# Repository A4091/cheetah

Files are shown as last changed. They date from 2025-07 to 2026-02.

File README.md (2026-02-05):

# A4770 Cheetah

A modern successor to the A4091 / A4092.

All the goodness of the A4092:
* TSSOP parts for smaller footprint
* SPI Flash instead of parallel EPROM
* CPLD instead of GALs
* Autoconfig moved into CPLD

And also:
* Update to NCR53c770 SCSI Host Controller
* Ultra-Wide SCSI support
* Drop unneeded ferrites and capacitors on SCSI lines
* Replace DIP-switch mechanism entirely w/ Software/Logic
* No more resistor arrays

# THIS IS WORK IN PROGRESS. DO NOT BUILD. FEEDBACK IS WELCOME

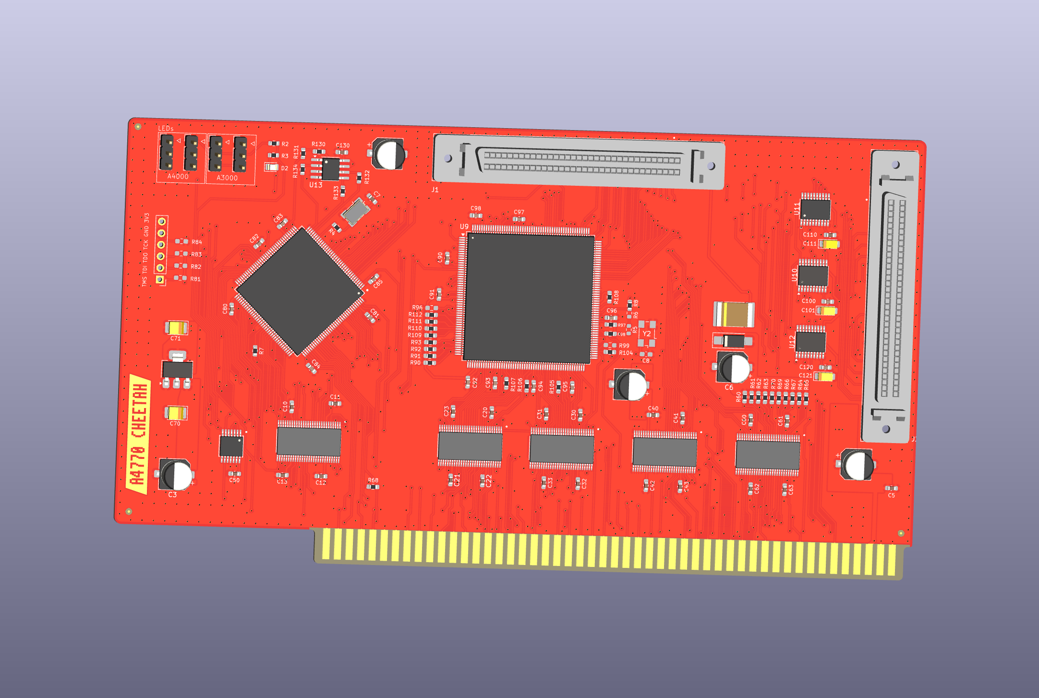
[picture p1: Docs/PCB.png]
PCB


<!-- ![PCB](Docs/PCB.png?raw=True)

And also as a real PCB:

![Real PCB](Docs/PCB.jpg?raw=True)

-->

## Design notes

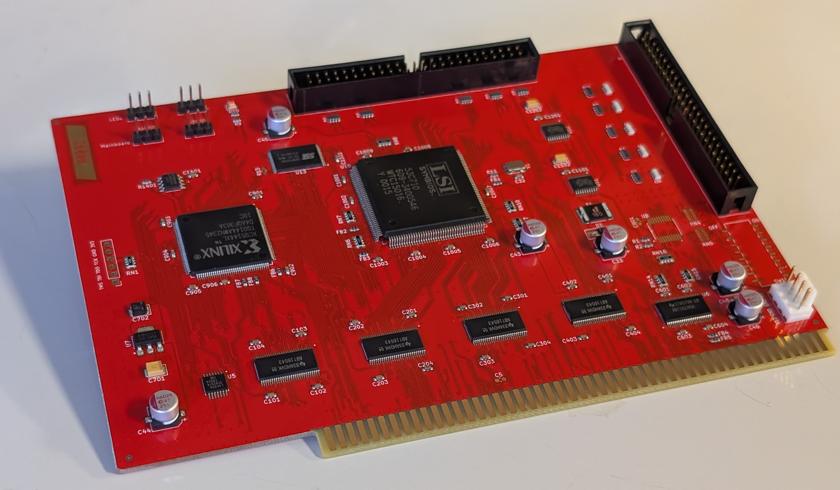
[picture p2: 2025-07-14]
Docs/PCB.jpg

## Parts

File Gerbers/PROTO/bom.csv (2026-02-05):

Designator | Footprint | Quantity | Value | LCSC Part #
C1, C2, C3, C4, C6 | CP_Elec_6.3x7.7 | 5 | 47uF | C369909
C10, C100, C11, C110, C12, C120, C13, C130, C20, C21, C22, C23, C30, C31, C32, C33, C40, C41, C42, C43, C5, C50, C60, C61, C62, C63, C80, C81, C82, C83, C84, C85, C90, C92, C94, C96, C98 | 0603 | 37 | 100nF | C14663
C101, C111, C121 | CP_EIA-3216-10_Kemet-I_HandSolder | 3 | 4.7uF | C7189
C7 | 0603 | 1 | 10nF | C57112
C70 | CP_EIA-3528-15_AVX-H_HandSolder | 1 | 10uF | C7194
C71 | CP_EIA-3528-15_AVX-H_HandSolder | 1 | 22uF | C696813
C91, C93, C95, C97 | 0603 | 4 | 100nF | C57112
D1 | D_SMA_Handsoldering | 1 | SS24 | C43381
D2 | 0805 | 1 | LED (green) | C965821
F1 | 2920 | 1 | ASMDC185F/33-2 | C135379
J1 | TE_5749721-7 | 1 | 5749721-7 | C591675
J2 | TE_5749721-7 | 1 | 5787082-7 | C591676
J3 | PinHeader_1x03_P2.54mm_Vertical | 1 | TO-LED | C6332196
J4 | PinHeader_1x03_P2.54mm_Vertical | 1 | TO-MB | C6332196
J5 | PinHeader_1x03_P2.54mm_Vertical | 1 | TO-A3000-LED | C6332196
J6 | PinHeader_1x03_P2.54mm_Vertical | 1 | TO-A3000-MB | C6332196
J8 | PinHeader_1x06_P2.54mm_Vertical | 1 | Conn_01x06_Pin | C6332199
R104, R105, R106, R107, R60, R61, R62, R63, R64, R65, R66, R67, R68, R69, R70, R90, R91, R92, R93, R96, R97, R98, R99 | 0603 | 23 | 1K | C21190
R108, R109, R110, R111, R112, R130, R81, R82, R83, R84 | 0603 | 10 | 10K | C25804
R131, R132, R133 | 0603 | 3 | 33 | C23140
R134, R8 | 0603 | 2 | 0 | C21189
R2 | 0603 | 1 | 120 | C22787
R3 | 0603 | 1 | 2.2k | C4190
R4, R7 | 0603 | 2 | 22 | C23345
U1, U2, U3, U4, U6 | DGG56 | 5 | SN74ABT16543DGGR | C2865087
U10, U11, U12 | TSSOP-20_4.4x6.5mm_P0.65mm | 3 | DS21S07A | C6602097
U13 | SOIC-8_multi | 1 | W25X40CLSN | C19617
U5 | TSSOP14_5P1X4P5_NEX | 1 | 74LVC07APW_118 | C6051
U7 | SOT-223-3_TabPin2 | 1 | AMS1117-3.3 | C6186
U8 | 144-TQFP_XIL | 1 | XC95144XL-TQ144 | C1521137
U9 | PQFP-208_28x28mm_P0.5mm | 1 | LSI53C770 SCSI Host Controller | C9900193416
Y1 | Oscillator_SMD_Fox_FT5H_5.0x3.2mm | 1 | Abracon ACO-50MHz | C7431196

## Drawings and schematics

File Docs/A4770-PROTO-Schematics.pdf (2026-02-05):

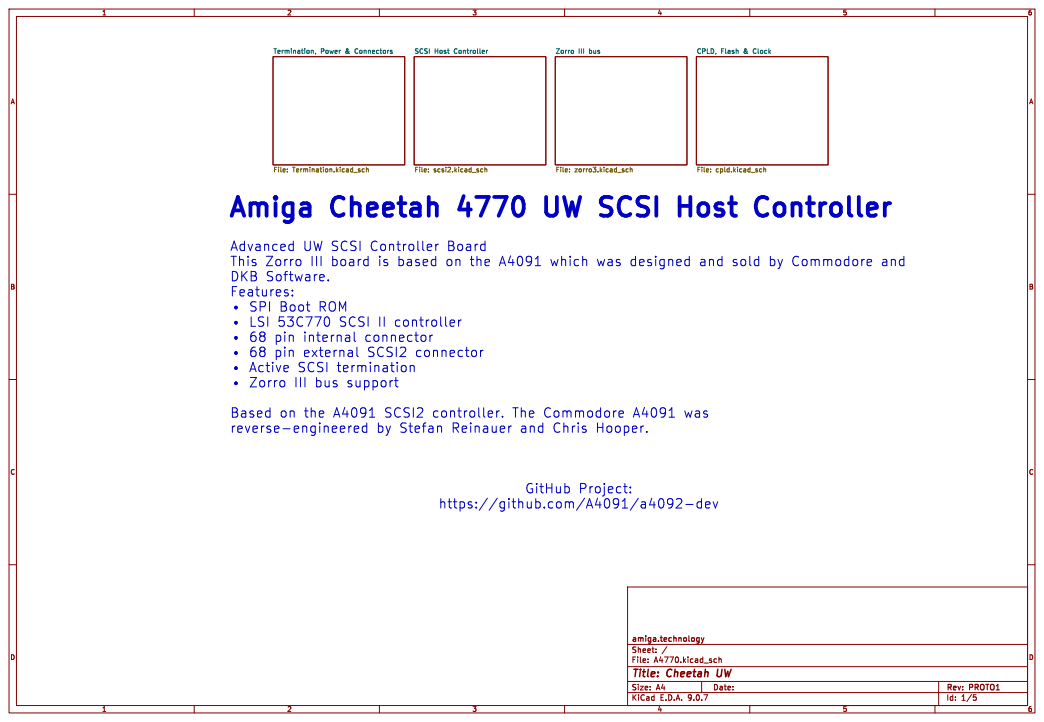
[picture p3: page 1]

Amiga Cheetah 4770 UW SCSI Host Controller

https://github.com/A4091/a4092-dev

File: A4770.kicad_sch Sheet: / amiga.technology

Id: 1/5 Title: Cheetah UW

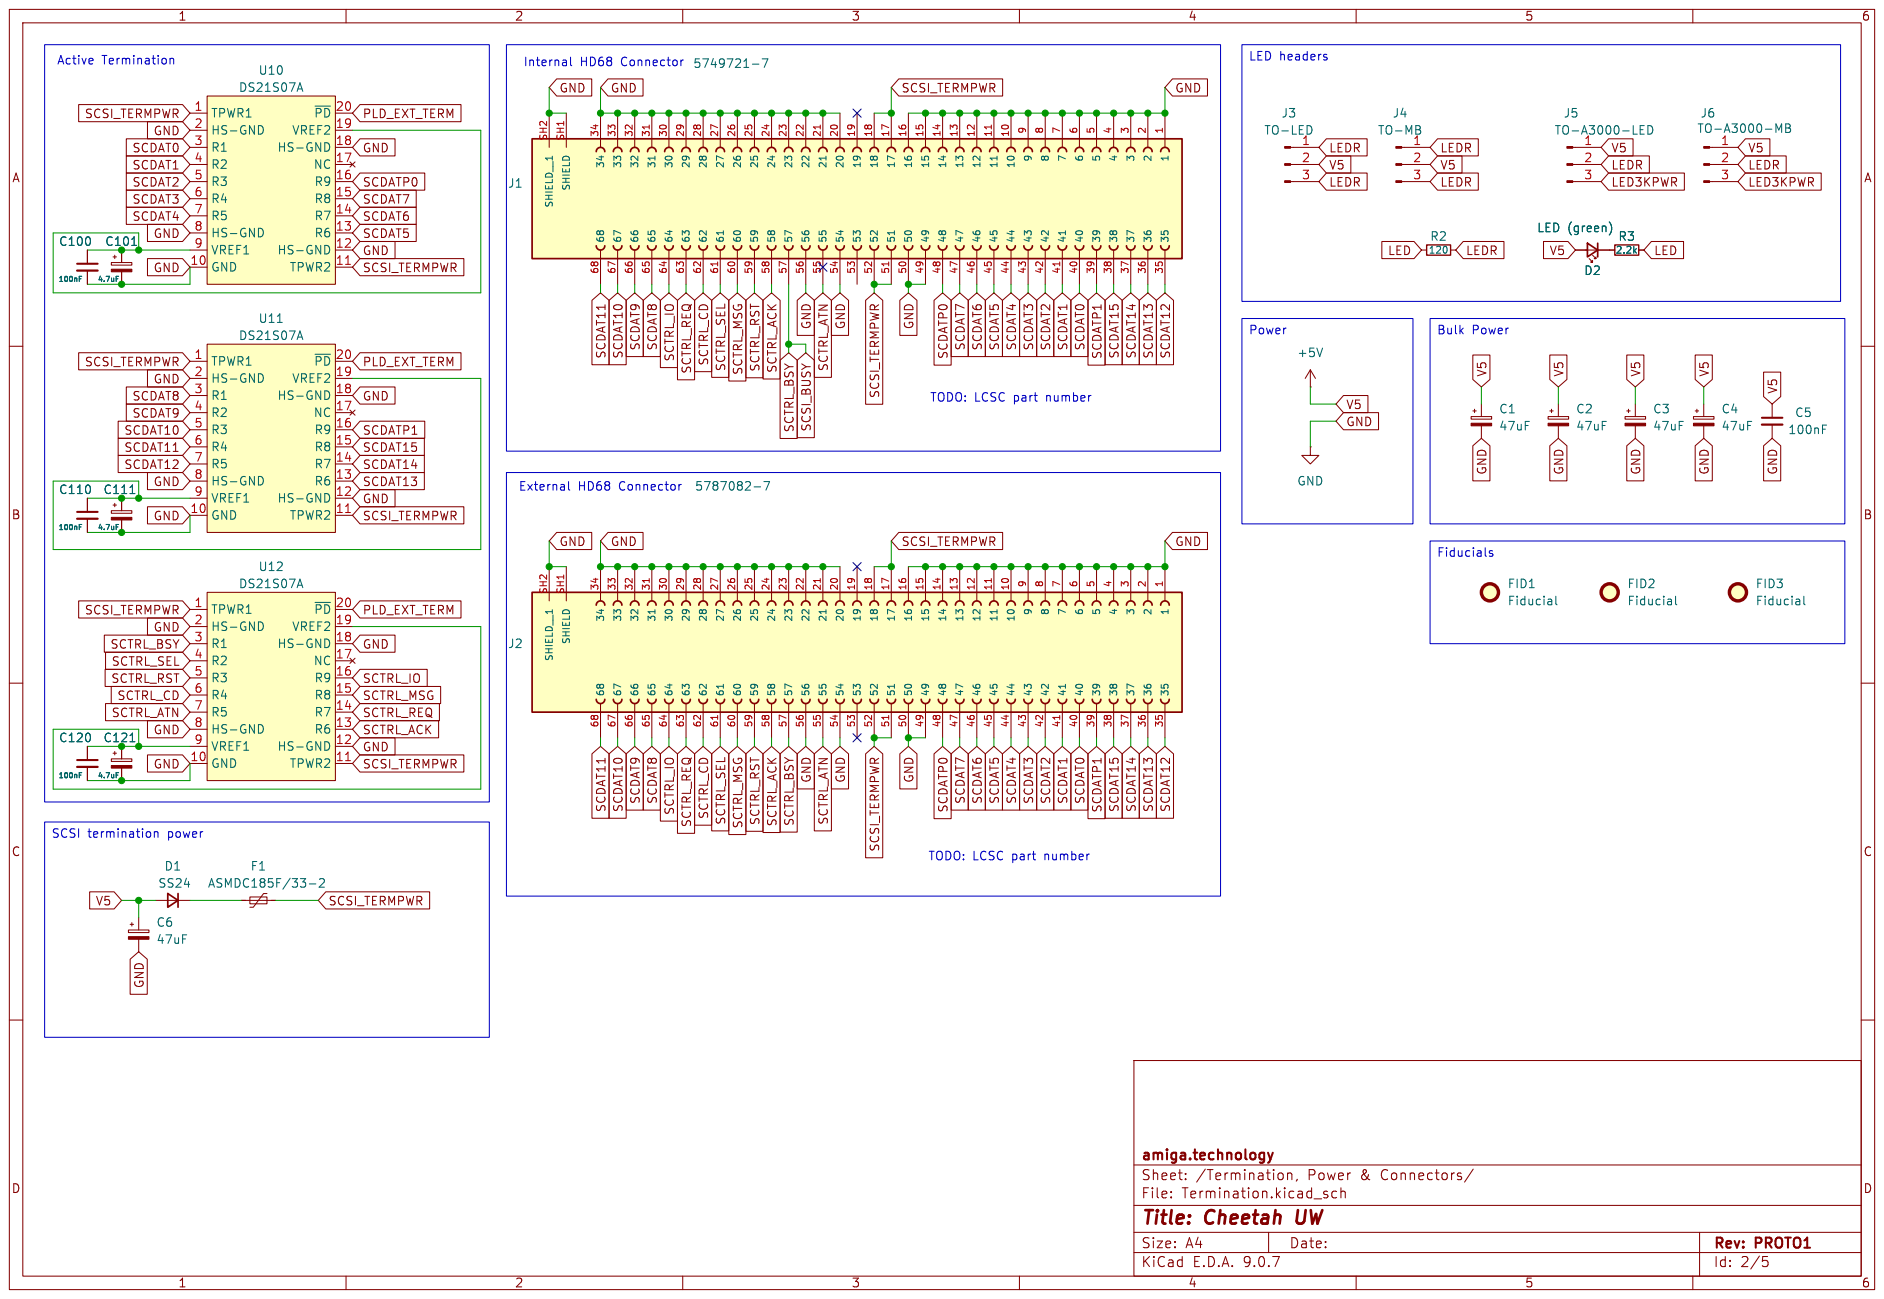
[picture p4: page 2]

LED headers Power External HD68 Connector Active Termination
SCSI_TERMPWR GND GND GND

TODO: LCSC part number

Id: 2/5 Title: Cheetah UW

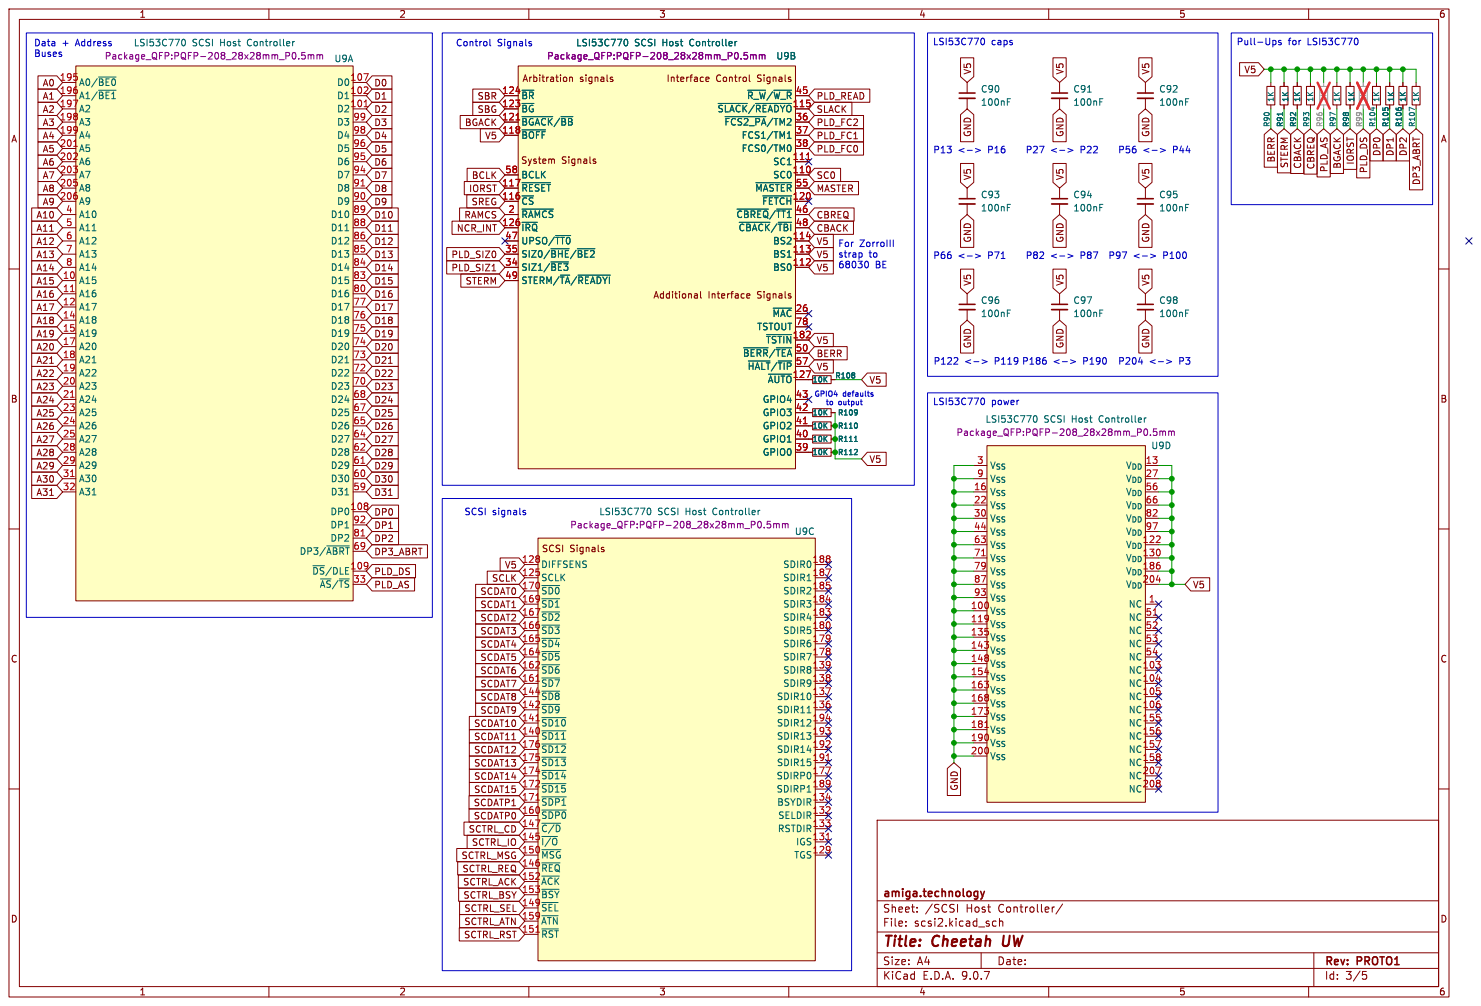
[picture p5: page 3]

Id: 3/5 Title: Cheetah UW

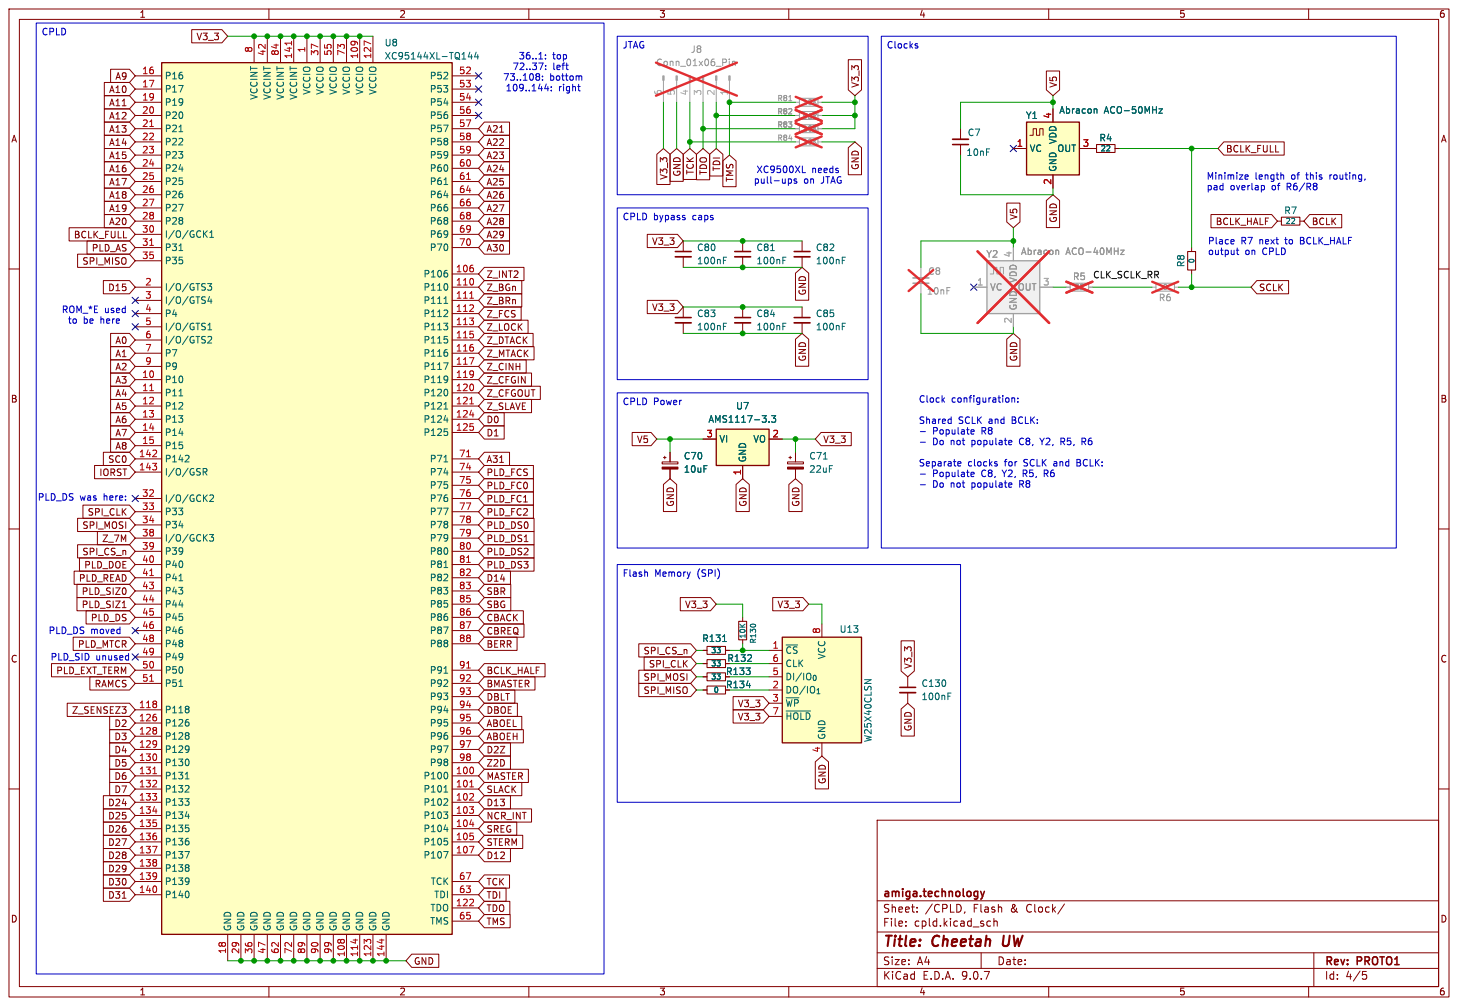
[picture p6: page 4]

8 GND 36 VCCINT 42 GND 47 VCCINT 84 GND 62 VCCINT 141 GND 72 VCCIO

1 GND 89 VCCIO 37 GND 90 VCCIO 55 GND 99 VCCIO 73 GND 108 VCCIO 109 GND 114 VCCIO 127 GND 123 GND 144 P52 52 P53 53 P54 54 P56 56 P57 57 P58 58 P59 59 P60 60 P61 61 P64 64 P66 66 P68 68 P69 69 P70 70 P106 106 P110 110 P111 111 P112 112 P113 113 P115 115 P116 116 P117 117 P119 119 P120 120 P121 121 P124 124 P125 125 P71 71 P74 74 P75 75 P76 76 P77 77 P78 78 P79 79 P80 80 P81 81 P82 82 P83 83 P85 85 P86 86 P87 87 P88 88 P91 91 P92 92 P93 93 P94 94 P95 95 P96 96 P97 97 P98 98 P100 100 P101 101 P102 102 P103 103 P104 104 P105 105 P107 107 TCK 67 TDI 63 TDO 122 TMS 65

JTAG
CPLD Power CPLD bypass caps

pad overlap of R6/R8 PLD_DS was here:
IORSTA3 A18

output on CPLD Minimize length of this routing,

Id: 4/5 Title: Cheetah UW

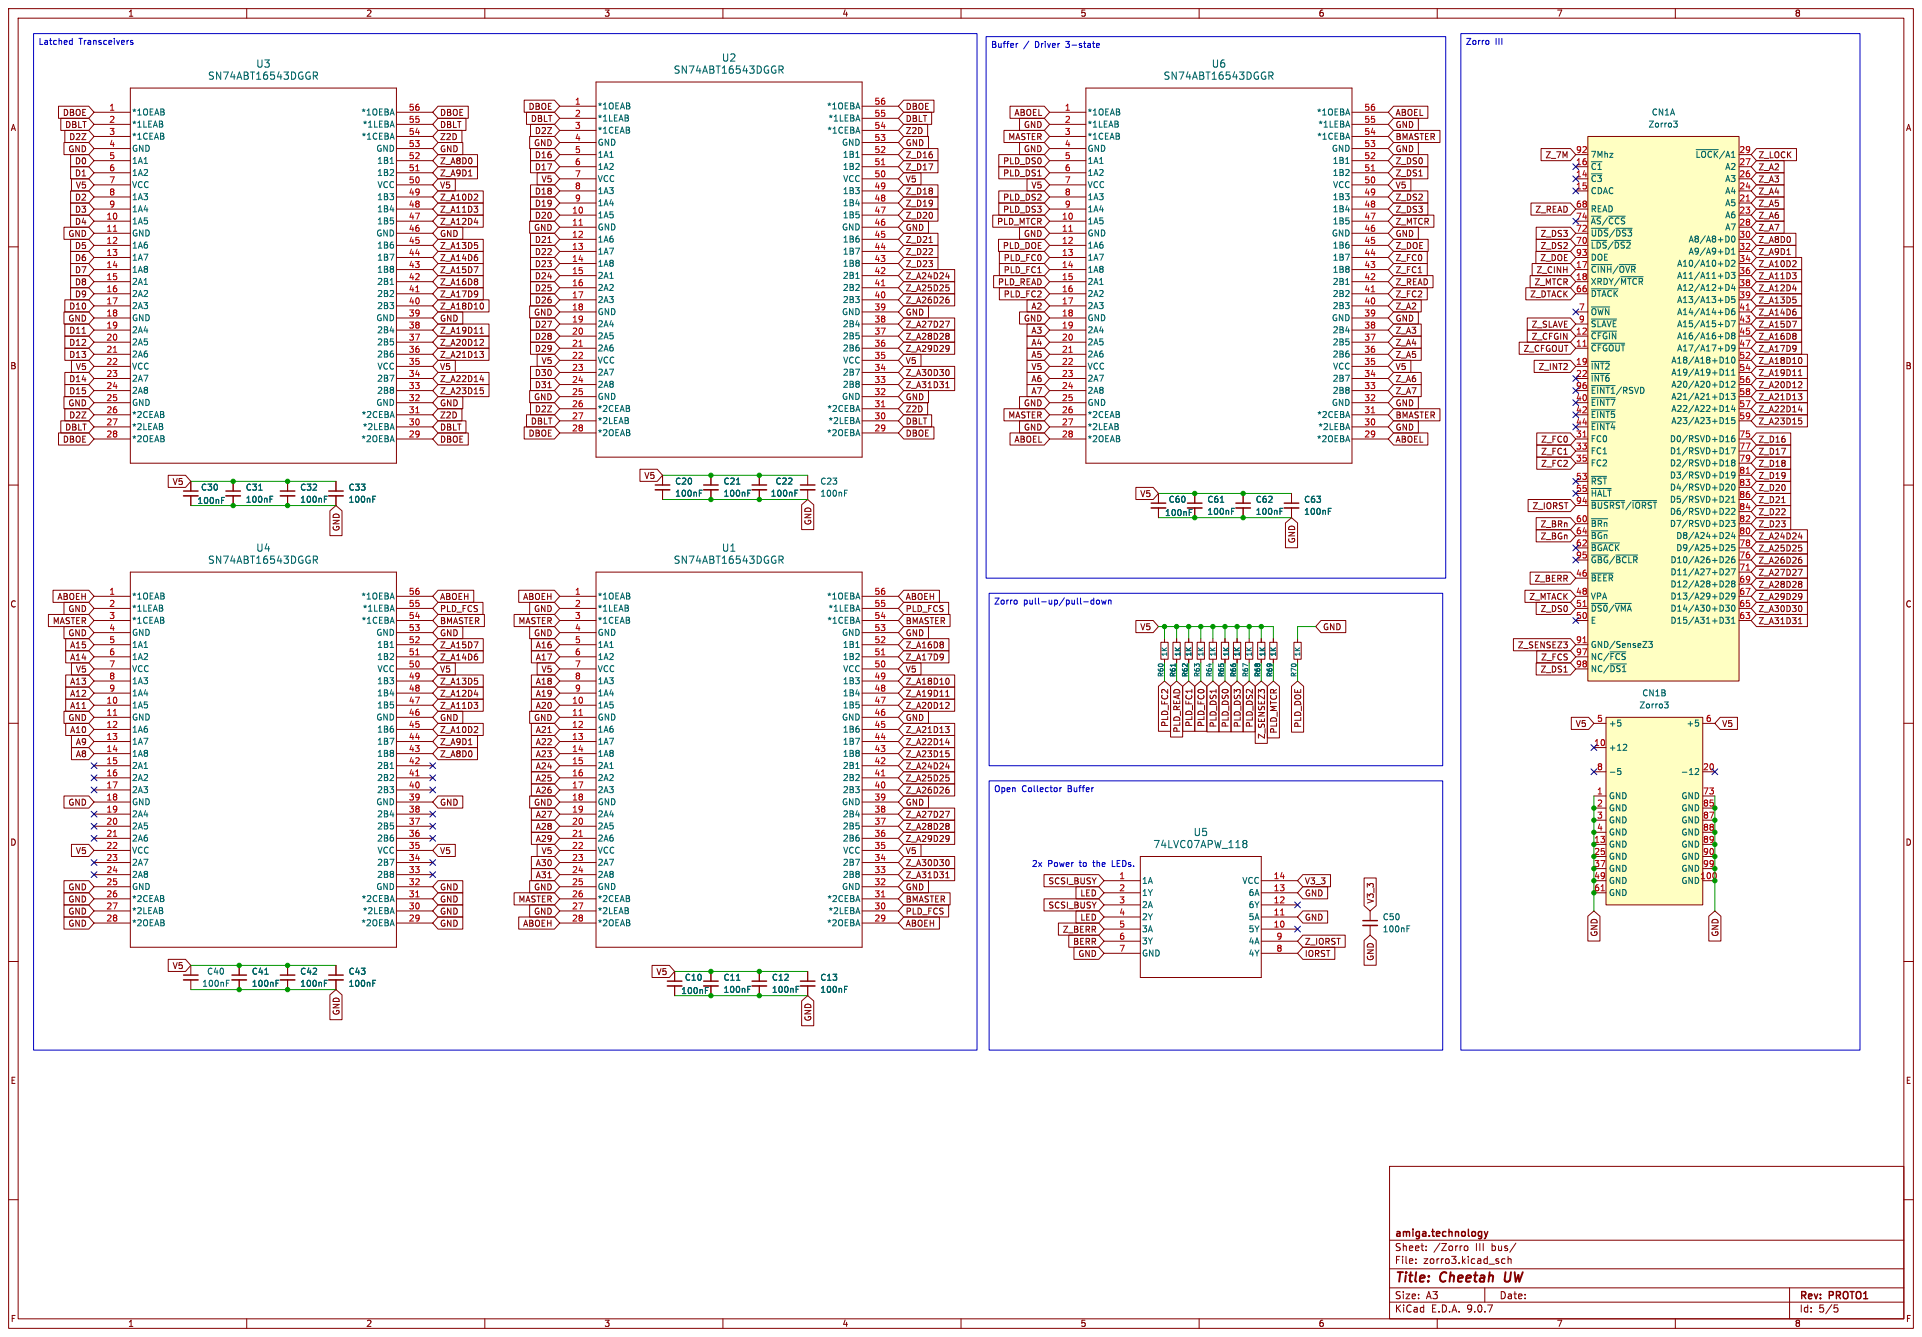
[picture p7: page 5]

Z_D17 Z_A23D15 Z_A13D5 Z_D16 Z_A2 Z_A3 Z_A6 Z_A5 Z_A7 Z_A4 DBOE
PLD_FC2 PLD_FC1 ABOEL GND MASTER GND

ABOEL Z_DS0 GND
7Mhz 92 ~{C1} 16 ~{C3} 14 CDAC 15 READ 68 ~{AS}/~{CCS} 74 ~{UDS}/~{DS3} 72 ~{LDS}/~{DS2} 70 DOE 93 ~{CINH}/~{OVR} 17 XRDY/~{MTCR} 18 ~{DTACK} 66 ~{OWN} 7 ~{SLAVE} 9 ~{CFGIN} 12 ~{CFGOUT} 11 ~{INT2} 19 ~{INT6} 22 ~{EINT1}/RSVD 96 ~{EINT7} 40 ~{EINT5} 42 ~{EINT4} 44 FC0 31 FC1 33 FC2 35 ~{RST} 53 ~{HALT} 55 ~{BUSRST}/~{IORST} 94 ~{BRn} 60 ~{BGn} 64 ~{BGACK} 62 ~{GBG}/~{BCLR} 95 ~{BEER} 46 VPA 48 ~{DS0}/~{VMA} 51 E

Z_MTCR GND GND GND GND GND GND

50 GND/SenseZ3 91 NC/~{FCS} 97 NC/~{DS1} 98

Id: 5/5 Title: Cheetah UW

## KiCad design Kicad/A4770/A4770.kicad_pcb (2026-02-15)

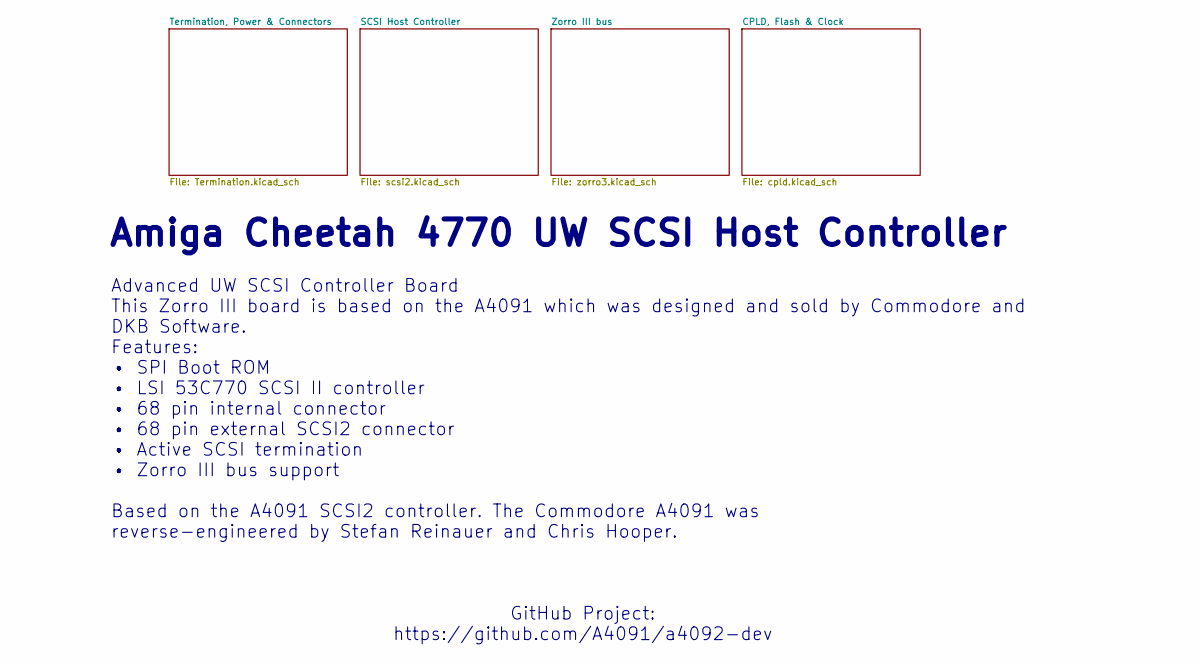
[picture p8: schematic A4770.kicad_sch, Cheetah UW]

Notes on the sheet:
Advanced UW SCSI Controller Board This Zorro III board is based on the A4091 which was designed and sold by Commodore and DKB Software. Features: • SPI Boot ROM • LSI 53C770 SCSI II controller • 68 pin internal connector • 68 pin external SCSI2 connector • Active SCSI termination • Zorro III bus su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
GitHub Project: https://github.com/A4091/a4092-dev
Amiga Cheetah 4770 UW SCSI Host Controller

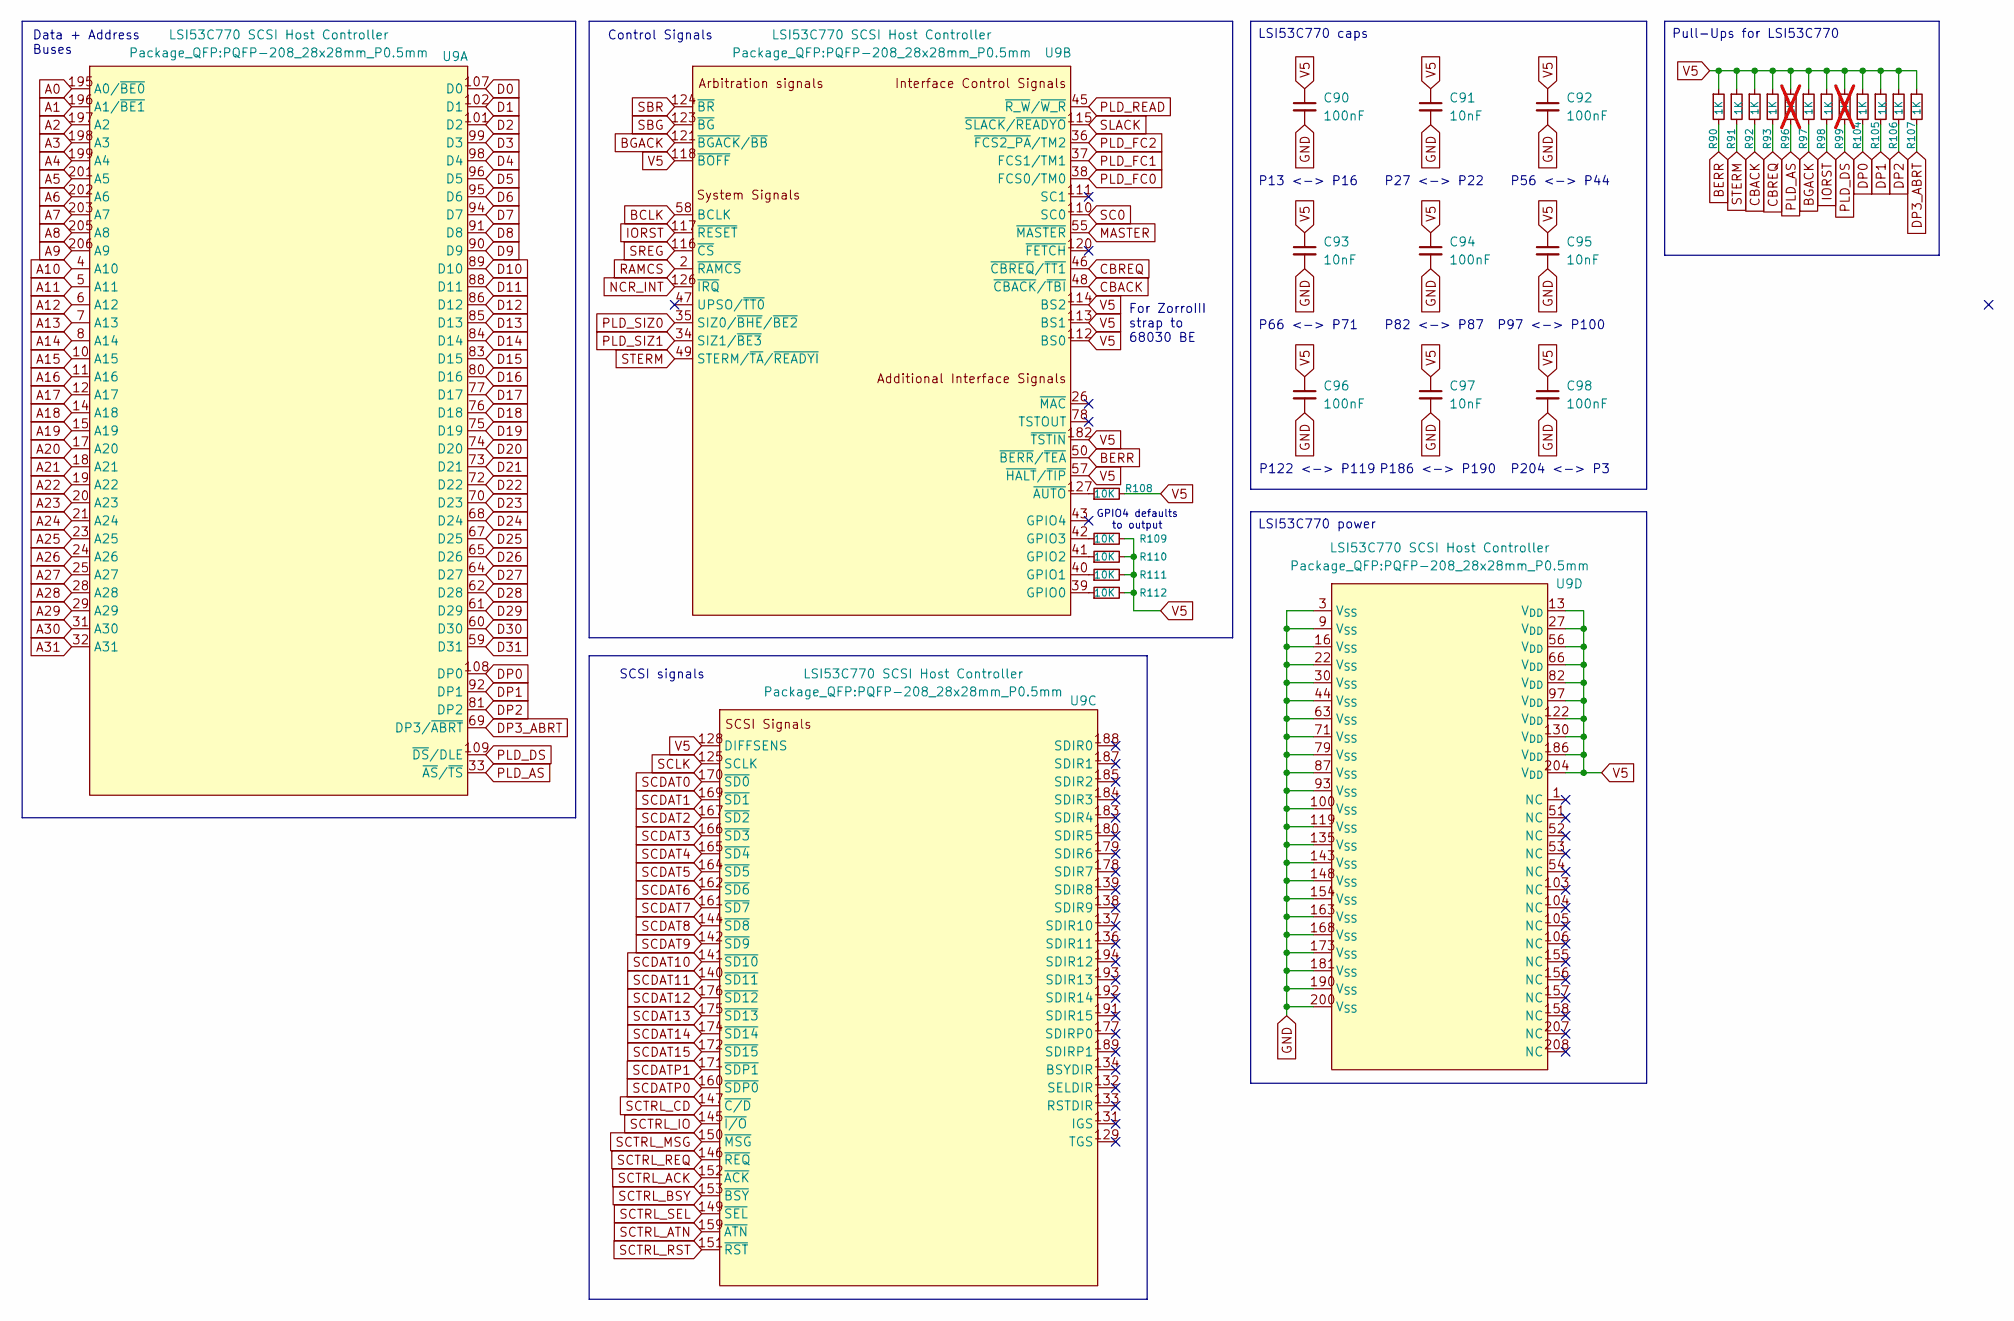
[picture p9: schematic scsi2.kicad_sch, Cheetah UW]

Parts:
C90, C92, C94, C96, C98: 100nF; C_0603_1608Metric_Pad1.08x0.95mm_HandSolder; LCSC Part # C14663
C91, C93, C95, C97: 10nF; C_0603_1608Metric_Pad1.08x0.95mm_HandSolder; LCSC Part # C57112
R90, R91, R92, R93, R97, R98, R104, R105, R106, R107: 1K; R_0603_1608Metric_Pad0.98x0.95mm_HandSolder; LCSC Part # C21190
R96, R99: 1K; R_0603_1608Metric_Pad0.98x0.95mm_HandSolder; LCSC Part # C21190; not fitted
R108, R109, R110, R111, R112: 10K; R_0603_1608Metric_Pad0.98x0.95mm_HandSolder; LCSC Part # C25804
U9: LSI53C770 SCSI Host Controller; PQFP-208_28x28mm_P0.5mm; LCSC Part # C9900193416

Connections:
A0: U9.195 (A0/~BE0); also elsewhere on the board
A1: U9.196 (A1/~BE1); also elsewhere on the board
A2: U9.197 (A2); also elsewhere on the board
A3: U9.198 (A3); also elsewhere on the board
A4: U9.199 (A4); also elsewhere on the board
A5: U9.201 (A5); also elsewhere on the board
A6: U9.202 (A6); also elsewhere on the board
A7: U9.203 (A7); also elsewhere on the board
A8: U9.205 (A8); also elsewhere on the board
A9: U9.206 (A9); also elsewhere on the board
A10: U9.4 (A10); also elsewhere on the board
A11: U9.5 (A11); also elsewhere on the board
A12: U9.6 (A12); also elsewhere on the board
A13: U9.7 (A13); also elsewhere on the board
A14: U9.8 (A14); also elsewhere on the board
A15: U9.10 (A15); also elsewhere on the board
A16: U9.11 (A16); also elsewhere on the board
A17: U9.12 (A17); also elsewhere on the board
A18: U9.14 (A18); also elsewhere on the board
A19: U9.15 (A19); also elsewhere on the board
A20: U9.17 (A20); also elsewhere on the board
A21: U9.18 (A21); also elsewhere on the board
A22: U9.19 (A22); also elsewhere on the board
A23: U9.20 (A23); also elsewhere on the board
A24: U9.21 (A24); also elsewhere on the board
A25: U9.23 (A25); also elsewhere on the board
A26: U9.24 (A26); also elsewhere on the board
A27: U9.25 (A27); also elsewhere on the board
A28: U9.28 (A28); also elsewhere on the board
A29: U9.29 (A29); also elsewhere on the board
A30: U9.31 (A30); also elsewhere on the board
A31: U9.32 (A31); also elsewhere on the board
BCLK: U9.58 (BCLK); also elsewhere on the board
BERR: R90.2, U9.50 (~BERR/~TEA); also elsewhere on the board
BGACK: R97.2, U9.121 (~BGACK/~BB)
CBACK: R92.2, U9.48 (~CBACK/~TBI); also elsewhere on the board
CBREQ: R93.2, U9.46 (~CBREQ/~TT1); also elsewhere on the board
D0: U9.107 (D0); also elsewhere on the board
D1: U9.102 (D1); also elsewhere on the board
D2: U9.101 (D2); also elsewhere on the board
D3: U9.99 (D3); also elsewhere on the board
D4: U9.98 (D4); also elsewhere on the board
D5: U9.96 (D5); also elsewhere on the board
D6: U9.95 (D6); also elsewhere on the board
D7: U9.94 (D7); also elsewhere on the board
D8: U9.91 (D8); also elsewhere on the board
D9: U9.90 (D9); also elsewhere on the board
D10: U9.89 (D10); also elsewhere on the board
D11: U9.88 (D11); also elsewhere on the board
D12: U9.86 (D12); also elsewhere on the board
D13: U9.85 (D13); also elsewhere on the board
D14: U9.84 (D14); also elsewhere on the board
D15: U9.83 (D15); also elsewhere on the board
D16: U9.80 (D16); also elsewhere on the board
D17: U9.77 (D17); also elsewhere on the board
D18: U9.76 (D18); also elsewhere on the board
D19: U9.75 (D19); also elsewhere on the board
D20: U9.74 (D20); also elsewhere on the board
D21: U9.73 (D21); also elsewhere on the board
D22: U9.72 (D22); also elsewhere on the board
D23: U9.70 (D23); also elsewhere on the board
D24: U9.68 (D24); also elsewhere on the board
D25: U9.67 (D25); also elsewhere on the board
D26: U9.65 (D26); also elsewhere on the board
D27: U9.64 (D27); also elsewhere on the board
D28: U9.62 (D28); also elsewhere on the board
D29: U9.61 (D29); also elsewhere on the board
D30: U9.60 (D30); also elsewhere on the board
D31: U9.59 (D31); also elsewhere on the board
DP0: R104.2, U9.108 (DP0)
DP1: R105.2, U9.92 (DP1)
DP2: R106.2, U9.81 (DP2)
DP3_ABRT: R107.2, U9.69 (DP3/~ABRT)
GND: C90.2, C91.2, C92.2, C93.2, C94.2, C95.2, C96.2, C97.2, C98.2, U9.3 (V_{SS}), U9.9 (V_{SS}), U9.16 (V_{SS}), U9.22 (V_{SS}), U9.30 (V_{SS}), U9.44 (V_{SS}), U9.63 (V_{SS}), U9.71 (V_{SS}), U9.79 (V_{SS}), U9.87 (V_{SS}), U9.93 (V_{SS}), U9.100 (V_{SS}), U9.119 (V_{SS}), U9.135 (V_{SS}), U9.143 (V_{SS}), U9.148 (V_{SS}), U9.154 (V_{SS}), U9.163 (V_{SS}), U9.168 (V_{SS}), U9.173 (V_{SS}), U9.181 (V_{SS}), U9.190 (V_{SS}), U9.200 (V_{SS}); also elsewhere on the board
IORST: R98.2, U9.117 (~RESET); also elsewhere on the board
MASTER: U9.55 (~MASTER); also elsewhere on the board
NCR_INT: U9.126 (~IRQ); also elsewhere on the board
unnamed: R112.1, U9.39 (GPIO0)
unnamed: R111.1, U9.40 (GPIO1)
unnamed: R110.1, U9.41 (GPIO2)
unnamed: R109.1, U9.42 (GPIO3)
unnamed: R108.1, U9.127 (~AUTO)
PLD_AS: R96.2, U9.33 (~AS/~TS); also elsewhere on the board
PLD_DS: R99.2, U9.109 (~DS/DLE); also elsewhere on the board
PLD_FC0: U9.38 (FCS0/TM0); also elsewhere on the board
PLD_FC1: U9.37 (FCS1/TM1); also elsewhere on the board
PLD_FC2: U9.36 (~FCS2_PA/TM2); also elsewhere on the board
PLD_READ: U9.45 (~R_W/~W_R); also elsewhere on the board
PLD_SIZ0: U9.35 (SIZ0/~BHE/~BE2); also elsewhere on the board
PLD_SIZ1: U9.34 (SIZ1/~BE3); also elsewhere on the board
RAMCS: U9.2 (~RAMCS); also elsewhere on the board
SBG: U9.123 (~BG); also elsewhere on the board
SBR: U9.124 (~BR); also elsewhere on the board
SC0: U9.110 (SC0); also elsewhere on the board
SCDAT0: U9.170 (~SD0); also elsewhere on the board
SCDAT1: U9.169 (~SD1); also elsewhere on the board
SCDAT2: U9.167 (~SD2); also elsewhere on the board
SCDAT3: U9.166 (~SD3); also elsewhere on the board
SCDAT4: U9.165 (~SD4); also elsewhere on the board
SCDAT5: U9.164 (~SD5); also elsewhere on the board
SCDAT6: U9.162 (~SD6); also elsewhere on the board
SCDAT7: U9.161 (~SD7); also elsewhere on the board
SCDAT8: U9.144 (~SD8); also elsewhere on the board
SCDAT9: U9.142 (~SD9); also elsewhere on the board
SCDAT10: U9.141 (~SD10); also elsewhere on the board
SCDAT11: U9.140 (~SD11); also elsewhere on the board
SCDAT12: U9.176 (~SD12); also elsewhere on the board
SCDAT13: U9.175 (~SD13); also elsewhere on the board
SCDAT14: U9.174 (~SD14); also elsewhere on the board
SCDAT15: U9.172 (~SD15); also elsewhere on the board
SCDATP0: U9.160 (~SDP0); also elsewhere on the board
SCDATP1: U9.171 (~SDP1); also elsewhere on the board
SCLK: U9.125 (SCLK); also elsewhere on the board
SCSI_BUSY: U9.153 (~BSY); also elsewhere on the board
SCTRL_ACK: U9.152 (~ACK); also elsewhere on the board
SCTRL_ATN: U9.159 (~ATN); also elsewhere on the board
SCTRL_CD: U9.147 (~C/D); also elsewhere on the board
SCTRL_IO: U9.145 (~I/O); also elsewhere on the board
SCTRL_MSG: U9.150 (~MSG); also elsewhere on the board
SCTRL_REQ: U9.146 (~REQ); also elsewhere on the board
SCTRL_RST: U9.151 (~RST); also elsewhere on the board
SCTRL_SEL: U9.149 (~SEL); also elsewhere on the board
SLACK: U9.115 (~SLACK/~READYO); also elsewhere on the board
SREG: U9.116 (~CS); also elsewhere on the board
STERM: R91.2, U9.49 (STERM/~TA/~READYI); also elsewhere on the board
V5: C90.1, C91.1, C92.1, C93.1, C94.1, C95.1, C96.1, C97.1, C98.1, R90.1, R91.1, R92.1, R93.1, R96.1, R97.1, R98.1, R99.1, R104.1, R105.1, R106.1, R107.1, R108.2, R109.2, R110.2, R111.2, R112.2, U9.13 (V_{DD}), U9.27 (V_{DD}), U9.56 (V_{DD}), U9.57 (~HALT/~TIP), U9.66 (V_{DD}), U9.82 (V_{DD}), U9.97 (V_{DD}), U9.112 (BS0), U9.113 (BS1), U9.114 (BS2), U9.118 (~BOFF), U9.122 (V_{DD}), U9.128 (DIFFSENS), U9.130 (V_{DD}), U9.182 (~TSTIN), U9.186 (V_{DD}), U9.204 (V_{DD}); also elsewhere on the board

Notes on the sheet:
P13 <-> P16
P122 <-> P119
P66 <-> P71
GPIO4 defaults to output
P186 <-> P190
SCSI signals
Control Signals
P204 <-> P3
P56 <-> P44
Data + Address Buses
P82 <-> P87
For ZorroIII strap to 68030 BE
P27 <-> P22
P97 <-> P100
LSI53C770 caps
LSI53C770 power
Pull-Ups for LSI53C770

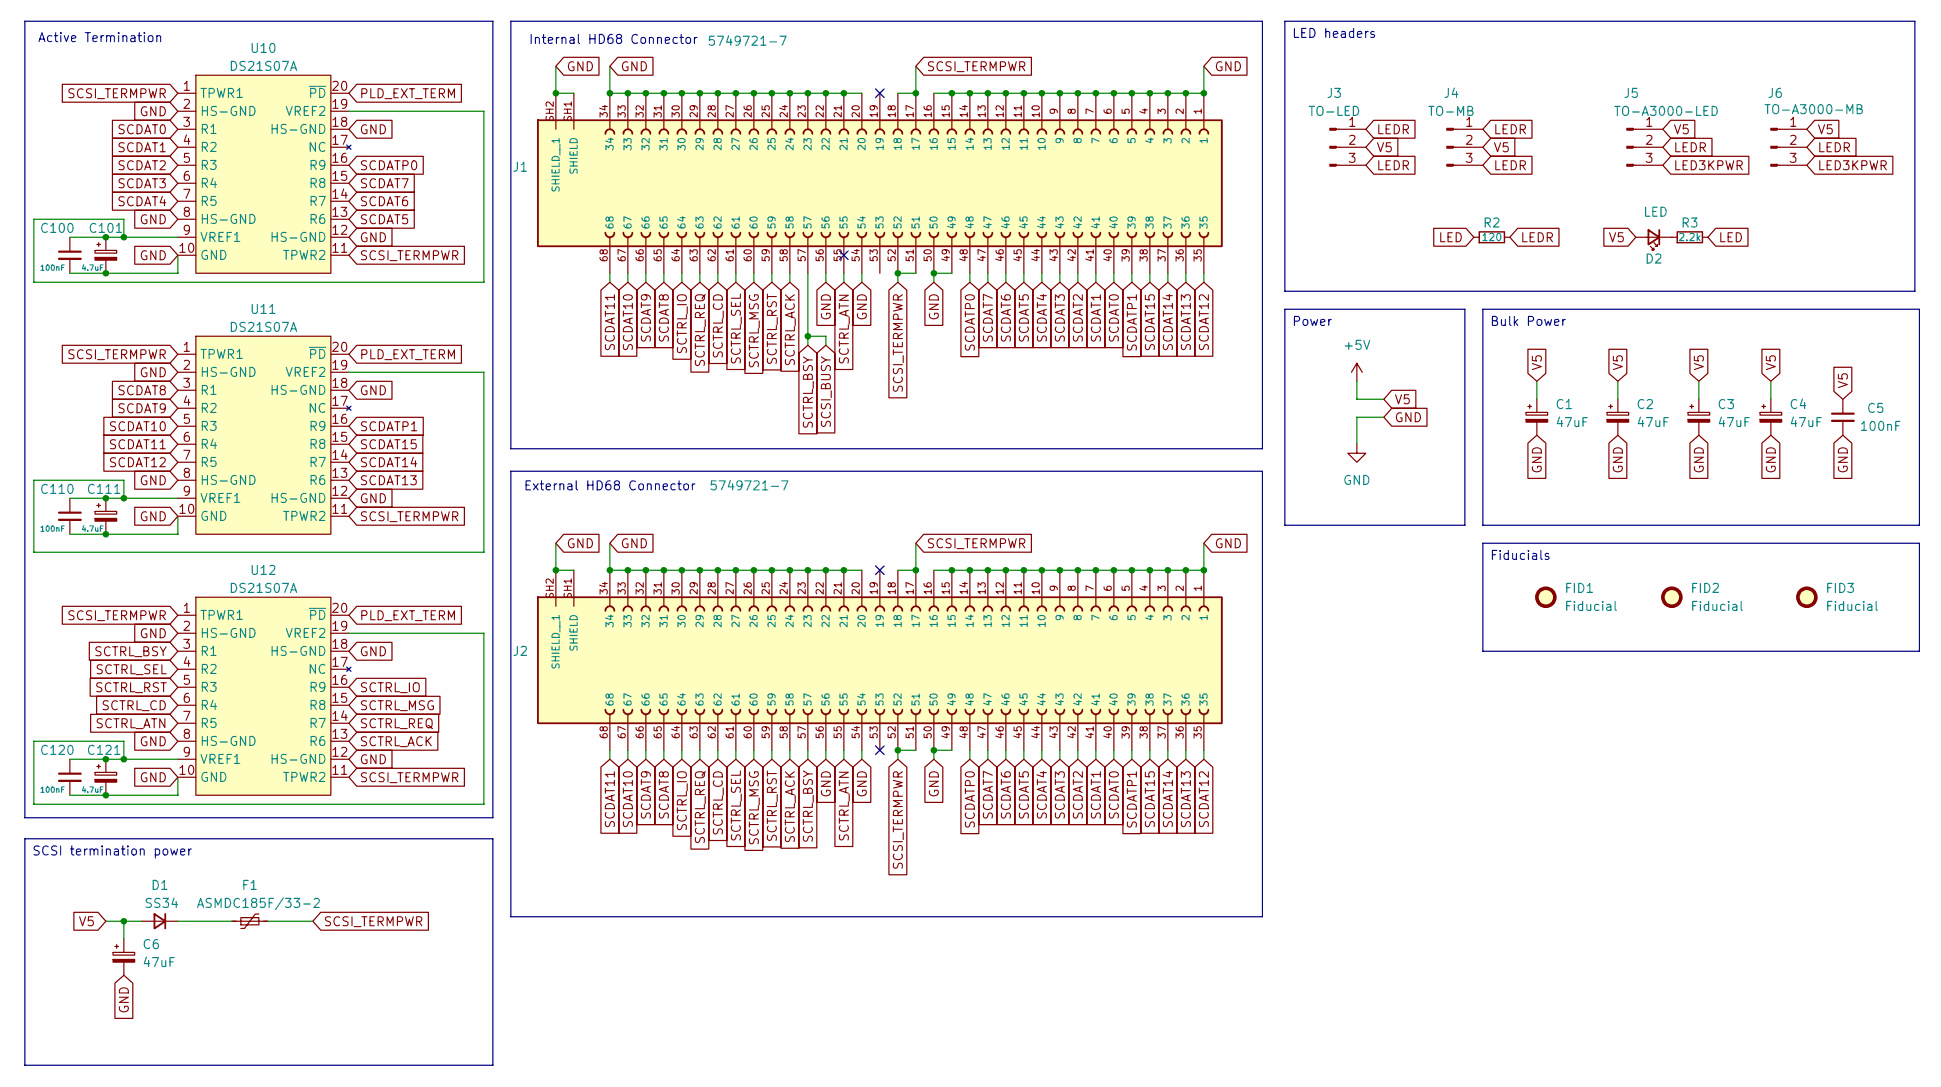
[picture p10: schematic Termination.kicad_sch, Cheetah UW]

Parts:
C1, C2, C3, C4, C6: 47uF; CP_Elec_6.3x7.7; MPN KEMET/A765EB476M1ELAE040; LCSC Part # C369909
C5, C100, C110, C120: 100nF; C_0603_1608Metric_Pad1.08x0.95mm_HandSolder; LCSC Part # C14663
C101, C111, C121: 4.7uF; CP_EIA-3216-10_Kemet-I_HandSolder; LCSC Part # C7189
D1: SS34; D_SMA_Handsoldering; LCSC Part # C466483
D2: LED; LED_0805_2012Metric; LCSC Part # C965821
F1: ASMDC185F/33-2; Fuse_2920_7451Metric_Pad2.10x5.45mm_HandSolder; LCSC Part # C780180
FID1, FID2, FID3: Fiducial; Fiducial_0.5mm_Mask1.5mm
J1, J2: 5749721-7; TE_5749721-7; PARTREV B1; LCSC Part # C591675
J3: TO-LED; PinHeader_1x03_P2.54mm_Vertical; LCSC Part # C6332196
J4: TO-MB; PinHeader_1x03_P2.54mm_Vertical; LCSC Part # C6332196
J5: TO-A3000-LED; PinHeader_1x03_P2.54mm_Vertical; LCSC Part # C6332196
J6: TO-A3000-MB; PinHeader_1x03_P2.54mm_Vertical; LCSC Part # C6332196
R2: 120; R_0603_1608Metric; LCSC Part # C22787
R3: 2.2k; R_0603_1608Metric; LCSC Part # C4190
U10, U11, U12: DS21S07A; TSSOP-20_4.4x6.5mm_P0.65mm; LCSC Part # C6602097

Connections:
GND: C1.2, C2.2, C3.2, C4.2, C5.2, C6.2, C100.2, C101.2, C110.2, C111.2, C120.2, C121.2, J1.1, J1.2, J1.3, J1.4, J1.5, J1.6, J1.7, J1.8, J1.9, J1.10, J1.11, J1.12, J1.13, J1.14, J1.15, J1.16, J1.20, J1.21, J1.22, J1.23, J1.24, J1.25, J1.26, J1.27, J1.28, J1.29, J1.30, J1.31, J1.32, J1.33, J1.34, J1.49, J1.50, J1.54, J1.56, J1.SH1 (SHIELD), J1.SH2 (SHIELD__1), J2.1, J2.2, J2.3, J2.4, J2.5, J2.6, J2.7, J2.8, J2.9, J2.10, J2.11, J2.12, J2.13, J2.14, J2.15, J2.16, J2.20, J2.21, J2.22, J2.23, J2.24, J2.25, J2.26, J2.27, J2.28, J2.29, J2.30, J2.31, J2.32, J2.33, J2.34, J2.49, J2.50, J2.54, J2.56, J2.SH1 (SHIELD), J2.SH2 (SHIELD__1), U10.2 (HS-GND), U10.8 (HS-GND), U10.10 (GND), U10.12 (HS-GND), U10.18 (HS-GND), U11.2 (HS-GND), U11.8 (HS-GND), U11.10 (GND), U11.12 (HS-GND), U11.18 (HS-GND), U12.2 (HS-GND), U12.8 (HS-GND), U12.10 (GND), U12.12 (HS-GND), U12.18 (HS-GND); also elsewhere on the board
LED: R2.1, R3.2; also elsewhere on the board
LED3KPWR: J5.3, J6.3
LEDR: J3.1, J3.3, J4.1, J4.3, J5.2, J6.2, R2.2
unnamed: D1.1 (K), F1.1
unnamed: D2.1 (K), R3.1
unnamed: C100.1, C101.1, U10.9 (VREF1), U10.19 (VREF2)
unnamed: C110.1, C111.1, U11.9 (VREF1), U11.19 (VREF2)
unnamed: C120.1, C121.1, U12.9 (VREF1), U12.19 (VREF2)
PLD_EXT_TERM: U10.20 (~PD), U11.20 (~PD), U12.20 (~PD); also elsewhere on the board
SCDAT0: J1.40, J2.40, U10.3 (R1); also elsewhere on the board
SCDAT1: J1.41, J2.41, U10.4 (R2); also elsewhere on the board
SCDAT2: J1.42, J2.42, U10.5 (R3); also elsewhere on the board
SCDAT3: J1.43, J2.43, U10.6 (R4); also elsewhere on the board
SCDAT4: J1.44, J2.44, U10.7 (R5); also elsewhere on the board
SCDAT5: J1.45, J2.45, U10.13 (R6); also elsewhere on the board
SCDAT6: J1.46, J2.46, U10.14 (R7); also elsewhere on the board
SCDAT7: J1.47, J2.47, U10.15 (R8); also elsewhere on the board
SCDAT8: J1.65, J2.65, U11.3 (R1); also elsewhere on the board
SCDAT9: J1.66, J2.66, U11.4 (R2); also elsewhere on the board
SCDAT10: J1.67, J2.67, U11.5 (R3); also elsewhere on the board
SCDAT11: J1.68, J2.68, U11.6 (R4); also elsewhere on the board
SCDAT12: J1.35, J2.35, U11.7 (R5); also elsewhere on the board
SCDAT13: J1.36, J2.36, U11.13 (R6); also elsewhere on the board
SCDAT14: J1.37, J2.37, U11.14 (R7); also elsewhere on the board
SCDAT15: J1.38, J2.38, U11.15 (R8); also elsewhere on the board
SCDATP0: J1.48, J2.48, U10.16 (R9); also elsewhere on the board
SCDATP1: J1.39, J2.39, U11.16 (R9); also elsewhere on the board
SCSI_BUSY: J1.57, J2.57, U12.3 (R1); also elsewhere on the board
SCSI_TERMPWR: F1.2, J1.17, J1.18, J1.51, J1.52, J2.17, J2.18, J2.51, J2.52, U10.1 (TPWR1), U10.11 (TPWR2), U11.1 (TPWR1), U11.11 (TPWR2), U12.1 (TPWR1), U12.11 (TPWR2)
SCTRL_ACK: J1.58, J2.58, U12.13 (R6); also elsewhere on the board
SCTRL_ATN: J1.55, J2.55, U12.7 (R5); also elsewhere on the board
SCTRL_CD: J1.62, J2.62, U12.6 (R4); also elsewhere on the board
SCTRL_IO: J1.64, J2.64, U12.16 (R9); also elsewhere on the board
SCTRL_MSG: J1.60, J2.60, U12.15 (R8); also elsewhere on the board
SCTRL_REQ: J1.63, J2.63, U12.14 (R7); also elsewhere on the board
SCTRL_RST: J1.59, J2.59, U12.5 (R3); also elsewhere on the board
SCTRL_SEL: J1.61, J2.61, U12.4 (R2); also elsewhere on the board
V5: C1.1, C2.1, C3.1, C4.1, C5.1, C6.1, D1.2 (A), D2.2 (A), J3.2, J4.2, J5.1, J6.1; also elsewhere on the board

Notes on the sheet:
Active Termination
Internal HD68 Connector
External HD68 Connector
SCSI termination power
Fiducials
Power
LED headers
Bulk Power

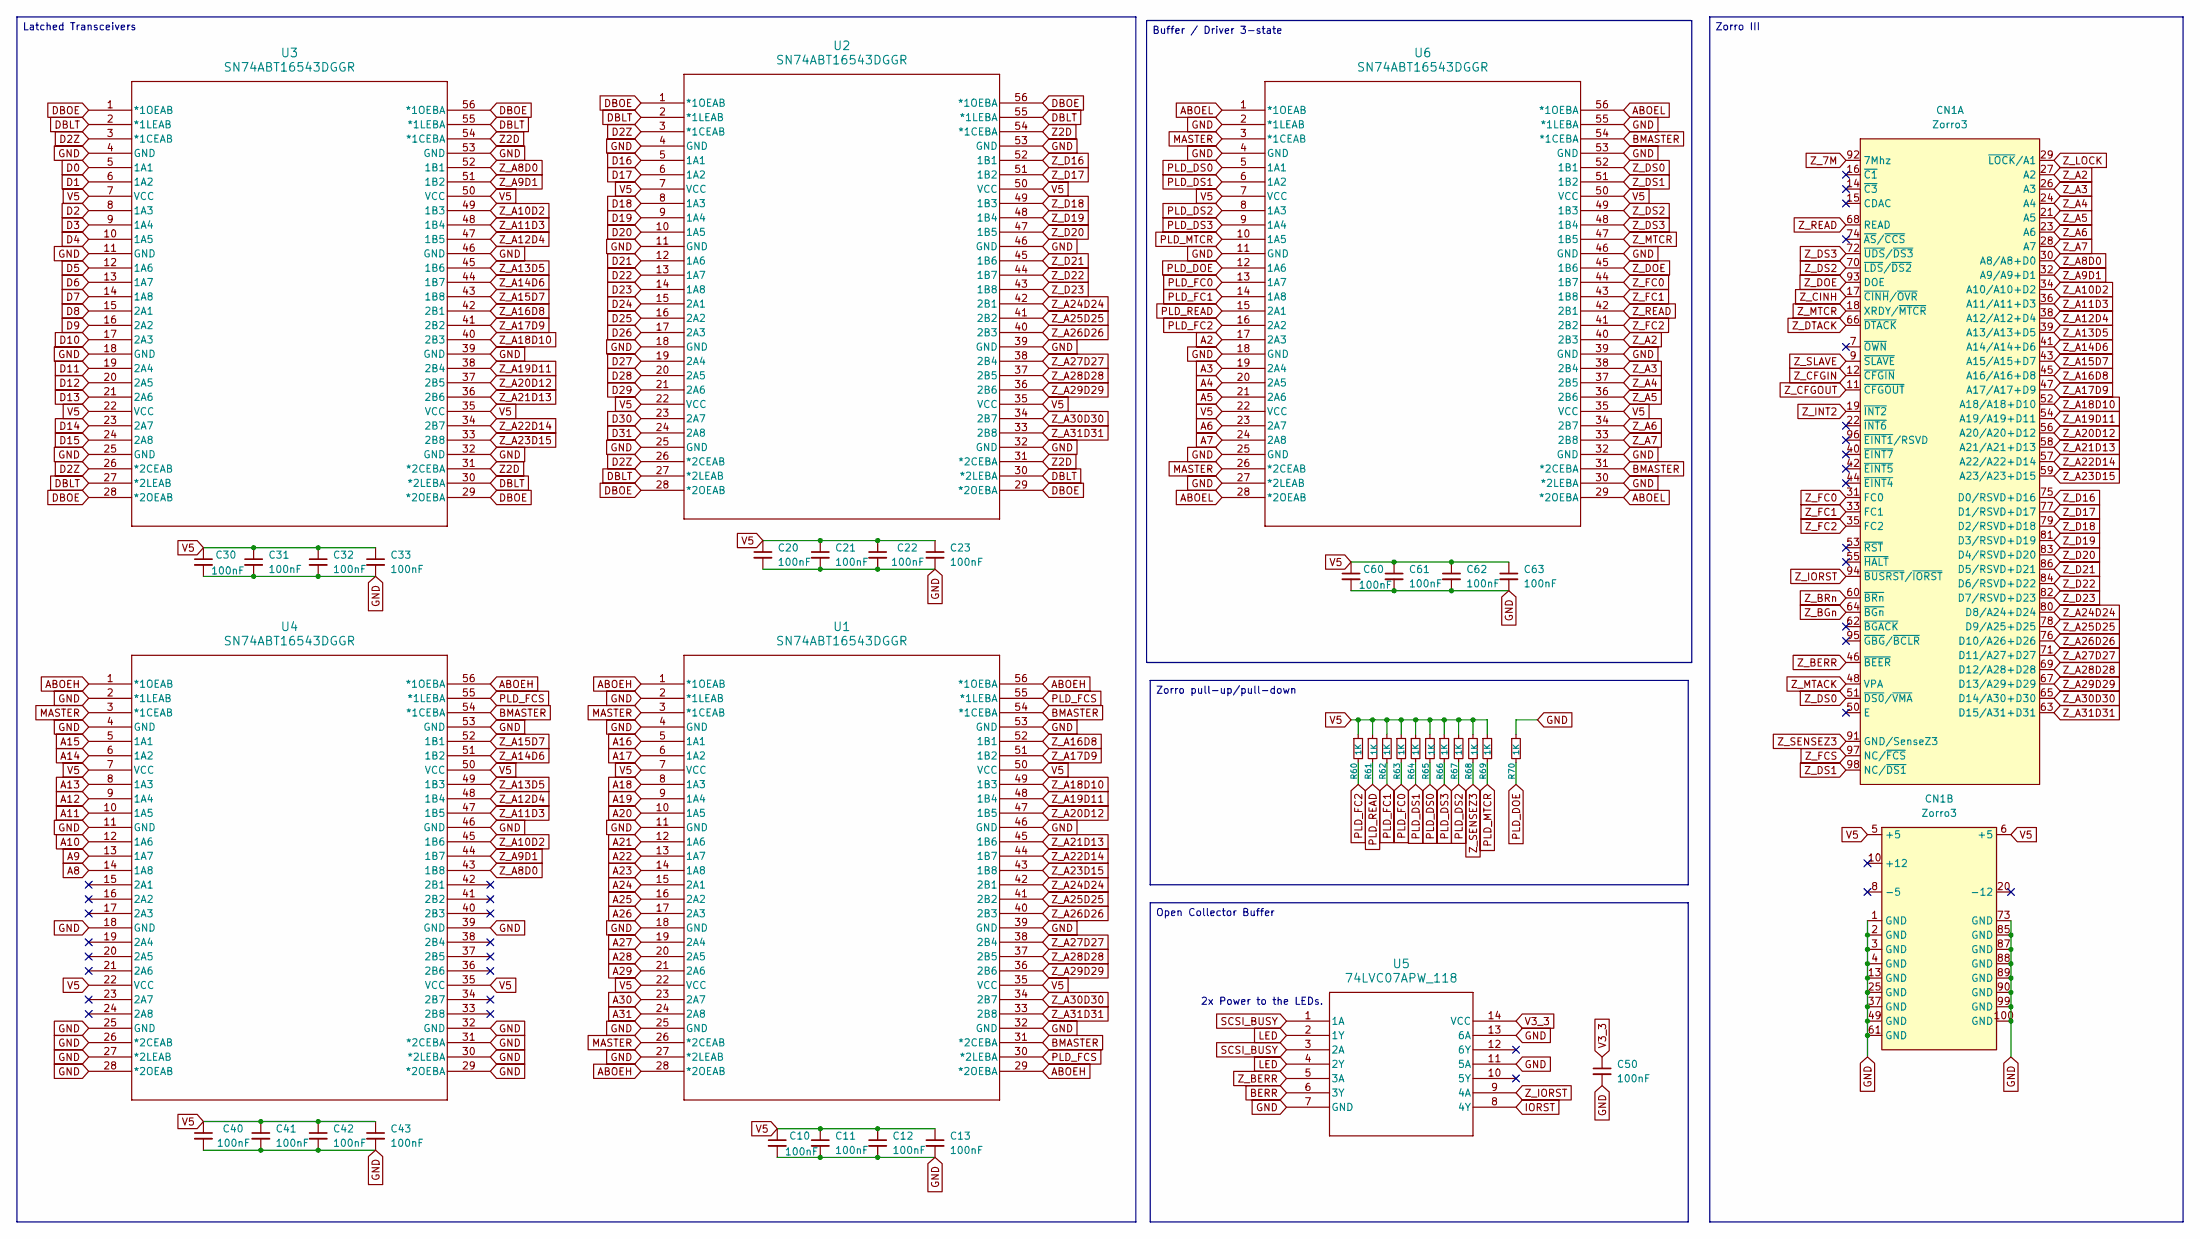
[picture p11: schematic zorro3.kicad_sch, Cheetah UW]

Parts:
C10, C11, C12, C13, C20, C21, C22, C23, C30, C31, C32, C33, C40, C41, C42, C43, C50, C60, C61, C62, C63: 100nF; C_0603_1608Metric_Pad1.08x0.95mm_HandSolder; LCSC Part # C14663
CN1: Zorro3; Zorro3-CardEdge
R60, R61, R62, R63, R64, R65, R66, R67, R68, R69, R70: 1K; R_0603_1608Metric_Pad0.98x0.95mm_HandSolder; LCSC Part # C21190
U1, U2, U3, U4, U6: SN74ABT16543DGGR; DGG56; LCSC Part # C2865087
U5: 74LVC07APW_118; TSSOP14_5P1X4P5_NEX; LCSC Part # C6051

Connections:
A2: U6.17 (2A3); also elsewhere on the board
A3: U6.19 (2A4); also elsewhere on the board
A4: U6.20 (2A5); also elsewhere on the board
A5: U6.21 (2A6); also elsewhere on the board
A6: U6.23 (2A7); also elsewhere on the board
A7: U6.24 (2A8); also elsewhere on the board
A8: U4.14 (1A8); also elsewhere on the board
A9: U4.13 (1A7); also elsewhere on the board
A10: U4.12 (1A6); also elsewhere on the board
A11: U4.10 (1A5); also elsewhere on the board
A12: U4.9 (1A4); also elsewhere on the board
A13: U4.8 (1A3); also elsewhere on the board
A14: U4.6 (1A2); also elsewhere on the board
A15: U4.5 (1A1); also elsewhere on the board
A16: U1.5 (1A1); also elsewhere on the board
A17: U1.6 (1A2); also elsewhere on the board
A18: U1.8 (1A3); also elsewhere on the board
A19: U1.9 (1A4); also elsewhere on the board
A20: U1.10 (1A5); also elsewhere on the board
A21: U1.12 (1A6); also elsewhere on the board
A22: U1.13 (1A7); also elsewhere on the board
A23: U1.14 (1A8); also elsewhere on the board
A24: U1.15 (2A1); also elsewhere on the board
A25: U1.16 (2A2); also elsewhere on the board
A26: U1.17 (2A3); also elsewhere on the board
A27: U1.19 (2A4); also elsewhere on the board
A28: U1.20 (2A5); also elsewhere on the board
A29: U1.21 (2A6); also elsewhere on the board
A30: U1.23 (2A7); also elsewhere on the board
A31: U1.24 (2A8); also elsewhere on the board
ABOEH: U1.1 (*1OEAB), U1.28 (*2OEAB), U1.29 (*2OEBA), U1.56 (*1OEBA), U4.1 (*1OEAB), U4.56 (*1OEBA); also elsewhere on the board
ABOEL: U6.1 (*1OEAB), U6.28 (*2OEAB), U6.29 (*2OEBA), U6.56 (*1OEBA); also elsewhere on the board
BERR: U5.6 (3Y); also elsewhere on the board
BMASTER: U1.31 (*2CEBA), U1.54 (*1CEBA), U4.54 (*1CEBA), U6.31 (*2CEBA), U6.54 (*1CEBA); also elsewhere on the board
D0: U3.5 (1A1); also elsewhere on the board
D1: U3.6 (1A2); also elsewhere on the board
D2: U3.8 (1A3); also elsewhere on the board
D2Z: U2.3 (*1CEAB), U2.26 (*2CEAB), U3.3 (*1CEAB), U3.26 (*2CEAB); also elsewhere on the board
D3: U3.9 (1A4); also elsewhere on the board
D4: U3.10 (1A5); also elsewhere on the board
D5: U3.12 (1A6); also elsewhere on the board
D6: U3.13 (1A7); also elsewhere on the board
D7: U3.14 (1A8); also elsewhere on the board
D8: U3.15 (2A1); also elsewhere on the board
D9: U3.16 (2A2); also elsewhere on the board
D10: U3.17 (2A3); also elsewhere on the board
D11: U3.19 (2A4); also elsewhere on the board
D12: U3.20 (2A5); also elsewhere on the board
D13: U3.21 (2A6); also elsewhere on the board
D14: U3.23 (2A7); also elsewhere on the board
D15: U3.24 (2A8); also elsewhere on the board
D16: U2.5 (1A1); also elsewhere on the board
D17: U2.6 (1A2); also elsewhere on the board
D18: U2.8 (1A3); also elsewhere on the board
D19: U2.9 (1A4); also elsewhere on the board
D20: U2.10 (1A5); also elsewhere on the board
D21: U2.12 (1A6); also elsewhere on the board
D22: U2.13 (1A7); also elsewhere on the board
D23: U2.14 (1A8); also elsewhere on the board
D24: U2.15 (2A1); also elsewhere on the board
D25: U2.16 (2A2); also elsewhere on the board
D26: U2.17 (2A3); also elsewhere on the board
D27: U2.19 (2A4); also elsewhere on the board
D28: U2.20 (2A5); also elsewhere on the board
D29: U2.21 (2A6); also elsewhere on the board
D30: U2.23 (2A7); also elsewhere on the board
D31: U2.24 (2A8); also elsewhere on the board
DBLT: U2.2 (*1LEAB), U2.27 (*2LEAB), U2.30 (*2LEBA), U2.55 (*1LEBA), U3.2 (*1LEAB), U3.27 (*2LEAB), U3.30 (*2LEBA), U3.55 (*1LEBA); also elsewhere on the board
DBOE: U2.1 (*1OEAB), U2.28 (*2OEAB), U2.29 (*2OEBA), U2.56 (*1OEBA), U3.1 (*1OEAB), U3.28 (*2OEAB), U3.29 (*2OEBA), U3.56 (*1OEBA); also elsewhere on the board
GND: C10.2, C11.2, C12.2, C13.2, C20.2, C21.2, C22.2, C23.2, C30.2, C31.2, C32.2, C33.2, C40.2, C41.2, C42.2, C43.2, C50.2, C60.2, C61.2, C62.2, C63.2, CN1.1 (GND), CN1.2 (GND), CN1.3 (GND), CN1.4 (GND), CN1.13 (GND), CN1.25 (GND), CN1.37 (GND), CN1.49 (GND), CN1.61 (GND), CN1.73 (GND), CN1.85 (GND), CN1.87 (GND), CN1.88 (GND), CN1.89 (GND), CN1.90 (GND), CN1.99 (GND), CN1.100 (GND), R70.1, U1.2 (*1LEAB), U1.4 (GND), U1.11 (GND), U1.18 (GND), U1.25 (GND), U1.27 (*2LEAB), U1.32 (GND), U1.39 (GND), U1.46 (GND), U1.53 (GND), U2.4 (GND), U2.11 (GND), U2.18 (GND), U2.25 (GND), U2.32 (GND), U2.39 (GND), U2.46 (GND), U2.53 (GND), U3.4 (GND), U3.11 (GND), U3.18 (GND), U3.25 (GND), U3.32 (GND), U3.39 (GND), U3.46 (GND), U3.53 (GND), U4.2 (*1LEAB), U4.4 (GND), U4.11 (GND), U4.18 (GND), U4.25 (GND), U4.26 (*2CEAB), U4.27 (*2LEAB), U4.28 (*2OEAB), U4.29 (*2OEBA), U4.30 (*2LEBA), U4.31 (*2CEBA), U4.32 (GND), U4.39 (GND), U4.46 (GND), U4.53 (GND), U5.7 (GND), U5.11 (5A), U5.13 (6A), U6.2 (*1LEAB), U6.4 (GND), U6.11 (GND), U6.18 (GND), U6.25 (GND), U6.27 (*2LEAB), U6.30 (*2LEBA), U6.32 (GND), U6.39 (GND), U6.46 (GND), U6.53 (GND), U6.55 (*1LEBA); also elsewhere on the board
IORST: U5.8 (4Y); also elsewhere on the board
LED: U5.2 (1Y), U5.4 (2Y); also elsewhere on the board
MASTER: U1.3 (*1CEAB), U1.26 (*2CEAB), U4.3 (*1CEAB), U6.3 (*1CEAB), U6.26 (*2CEAB); also elsewhere on the board
PLD_DOE: R70.2, U6.12 (1A6); also elsewhere on the board
PLD_DS0: R65.2, U6.5 (1A1); also elsewhere on the board
PLD_DS1: R64.2, U6.6 (1A2); also elsewhere on the board
PLD_DS2: R67.2, U6.8 (1A3); also elsewhere on the board
PLD_DS3: R66.2, U6.9 (1A4); also elsewhere on the board
PLD_FC0: R63.2, U6.13 (1A7); also elsewhere on the board
PLD_FC1: R62.2, U6.14 (1A8); also elsewhere on the board
PLD_FC2: R60.2, U6.16 (2A2); also elsewhere on the board
PLD_FCS: U1.30 (*2LEBA), U1.55 (*1LEBA), U4.55 (*1LEBA); also elsewhere on the board
PLD_MTCR: R69.2, U6.10 (1A5); also elsewhere on the board
PLD_READ: R61.2, U6.15 (2A1); also elsewhere on the board
SCSI_BUSY: U5.1 (1A), U5.3 (2A); also elsewhere on the board
V3_3: C50.1, U5.14 (VCC); also elsewhere on the board
V5: C10.1, C11.1, C12.1, C13.1, C20.1, C21.1, C22.1, C23.1, C30.1, C31.1, C32.1, C33.1, C40.1, C41.1, C42.1, C43.1, C60.1, C61.1, C62.1, C63.1, CN1.5 (+5), CN1.6 (+5), R60.1, R61.1, R62.1, R63.1, R64.1, R65.1, R66.1, R67.1, R68.1, R69.1, U1.7 (VCC), U1.22 (VCC), U1.35 (VCC), U1.50 (VCC), U2.7 (VCC), U2.22 (VCC), U2.35 (VCC), U2.50 (VCC), U3.7 (VCC), U3.22 (VCC), U3.35 (VCC), U3.50 (VCC), U4.7 (VCC), U4.22 (VCC), U4.35 (VCC), U4.50 (VCC), U6.7 (VCC), U6.22 (VCC), U6.35 (VCC), U6.50 (VCC); also elsewhere on the board
Z2D: U2.31 (*2CEBA), U2.54 (*1CEBA), U3.31 (*2CEBA), U3.54 (*1CEBA); also elsewhere on the board
Z_7M: CN1.92 (7Mhz); also elsewhere on the board
Z_A2: CN1.27 (A2), U6.40 (2B3)
Z_A3: CN1.26 (A3), U6.38 (2B4)
Z_A4: CN1.24 (A4), U6.37 (2B5)
Z_A5: CN1.21 (A5), U6.36 (2B6)
Z_A6: CN1.23 (A6), U6.34 (2B7)
Z_A7: CN1.28 (A7), U6.33 (2B8)
Z_A8D0: CN1.30 (A8/A8+D0), U3.52 (1B1), U4.43 (1B8)
Z_A9D1: CN1.32 (A9/A9+D1), U3.51 (1B2), U4.44 (1B7)
Z_A10D2: CN1.34 (A10/A10+D2), U3.49 (1B3), U4.45 (1B6)
Z_A11D3: CN1.36 (A11/A11+D3), U3.48 (1B4), U4.47 (1B5)
Z_A12D4: CN1.38 (A12/A12+D4), U3.47 (1B5), U4.48 (1B4)
Z_A13D5: CN1.39 (A13/A13+D5), U3.45 (1B6), U4.49 (1B3)
Z_A14D6: CN1.41 (A14/A14+D6), U3.44 (1B7), U4.51 (1B2)
Z_A15D7: CN1.43 (A15/A15+D7), U3.43 (1B8), U4.52 (1B1)
Z_A16D8: CN1.45 (A16/A16+D8), U1.52 (1B1), U3.42 (2B1)
Z_A17D9: CN1.47 (A17/A17+D9), U1.51 (1B2), U3.41 (2B2)
Z_A18D10: CN1.52 (A18/A18+D10), U1.49 (1B3), U3.40 (2B3)
Z_A19D11: CN1.54 (A19/A19+D11), U1.48 (1B4), U3.38 (2B4)
Z_A20D12: CN1.56 (A20/A20+D12), U1.47 (1B5), U3.37 (2B5)
Z_A21D13: CN1.58 (A21/A21+D13), U1.45 (1B6), U3.36 (2B6)
Z_A22D14: CN1.57 (A22/A22+D14), U1.44 (1B7), U3.34 (2B7)
Z_A23D15: CN1.59 (A23/A23+D15), U1.43 (1B8), U3.33 (2B8)
Z_A24D24: CN1.80 (D8/A24+D24), U1.42 (2B1), U2.42 (2B1)
Z_A25D25: CN1.78 (D9/A25+D25), U1.41 (2B2), U2.41 (2B2)
Z_A26D26: CN1.76 (D10/A26+D26), U1.40 (2B3), U2.40 (2B3)
Z_A27D27: CN1.71 (D11/A27+D27), U1.38 (2B4), U2.38 (2B4)
Z_A28D28: CN1.69 (D12/A28+D28), U1.37 (2B5), U2.37 (2B5)
Z_A29D29: CN1.67 (D13/A29+D29), U1.36 (2B6), U2.36 (2B6)
Z_A30D30: CN1.65 (D14/A30+D30), U1.34 (2B7), U2.34 (2B7)
Z_A31D31: CN1.63 (D15/A31+D31), U1.33 (2B8), U2.33 (2B8)
Z_BERR: CN1.46 (~BEER), U5.5 (3A)
Z_BGn: CN1.64 (~BGn); also elsewhere on the board
Z_BRn: CN1.60 (~BRn); also elsewhere on the board
Z_CFGIN: CN1.12 (~CFGIN); also elsewhere on the board
Z_CFGOUT: CN1.11 (~CFGOUT); also elsewhere on the board
Z_CINH: CN1.17 (~CINH/~OVR); also elsewhere on the board
Z_D16: CN1.75 (D0/RSVD+D16), U2.52 (1B1)
Z_D17: CN1.77 (D1/RSVD+D17), U2.51 (1B2)
Z_D18: CN1.79 (D2/RSVD+D18), U2.49 (1B3)
Z_D19: CN1.81 (D3/RSVD+D19), U2.48 (1B4)
Z_D20: CN1.83 (D4/RSVD+D20), U2.47 (1B5)
Z_D21: CN1.86 (D5/RSVD+D21), U2.45 (1B6)
Z_D22: CN1.84 (D6/RSVD+D22), U2.44 (1B7)
Z_D23: CN1.82 (D7/RSVD+D23), U2.43 (1B8)
Z_DOE: CN1.93 (DOE), U6.45 (1B6)
Z_DS0: CN1.51 (~DS0/~VMA), U6.52 (1B1)
Z_DS1: CN1.98 (NC/~DS1), U6.51 (1B2)
Z_DS2: CN1.70 (~LDS/~DS2), U6.49 (1B3)
Z_DS3: CN1.72 (~UDS/~DS3), U6.48 (1B4)
Z_DTACK: CN1.66 (~DTACK); also elsewhere on the board
Z_FC0: CN1.31 (FC0), U6.44 (1B7)
Z_FC1: CN1.33 (FC1), U6.43 (1B8)
Z_FC2: CN1.35 (FC2), U6.41 (2B2)
Z_FCS: CN1.97 (NC/~FCS); also elsewhere on the board
Z_INT2: CN1.19 (~INT2); also elsewhere on the board
Z_IORST: CN1.94 (~BUSRST/~IORST), U5.9 (4A)
Z_LOCK: CN1.29 (~LOCK/A1); also elsewhere on the board
Z_MTACK: CN1.48 (VPA); also elsewhere on the board
Z_MTCR: CN1.18 (XRDY/~MTCR), U6.47 (1B5)
Z_READ: CN1.68 (READ), U6.42 (2B1)
Z_SENSEZ3: CN1.91 (GND/SenseZ3), R68.2; also elsewhere on the board
Z_SLAVE: CN1.9 (~SLAVE); also elsewhere on the board

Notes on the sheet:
2x Power to the LEDs.
Buffer / Driver 3-state
Zorro pull-up/pull-down
Latched Transceivers
Open Collector Buffer
Zorro III

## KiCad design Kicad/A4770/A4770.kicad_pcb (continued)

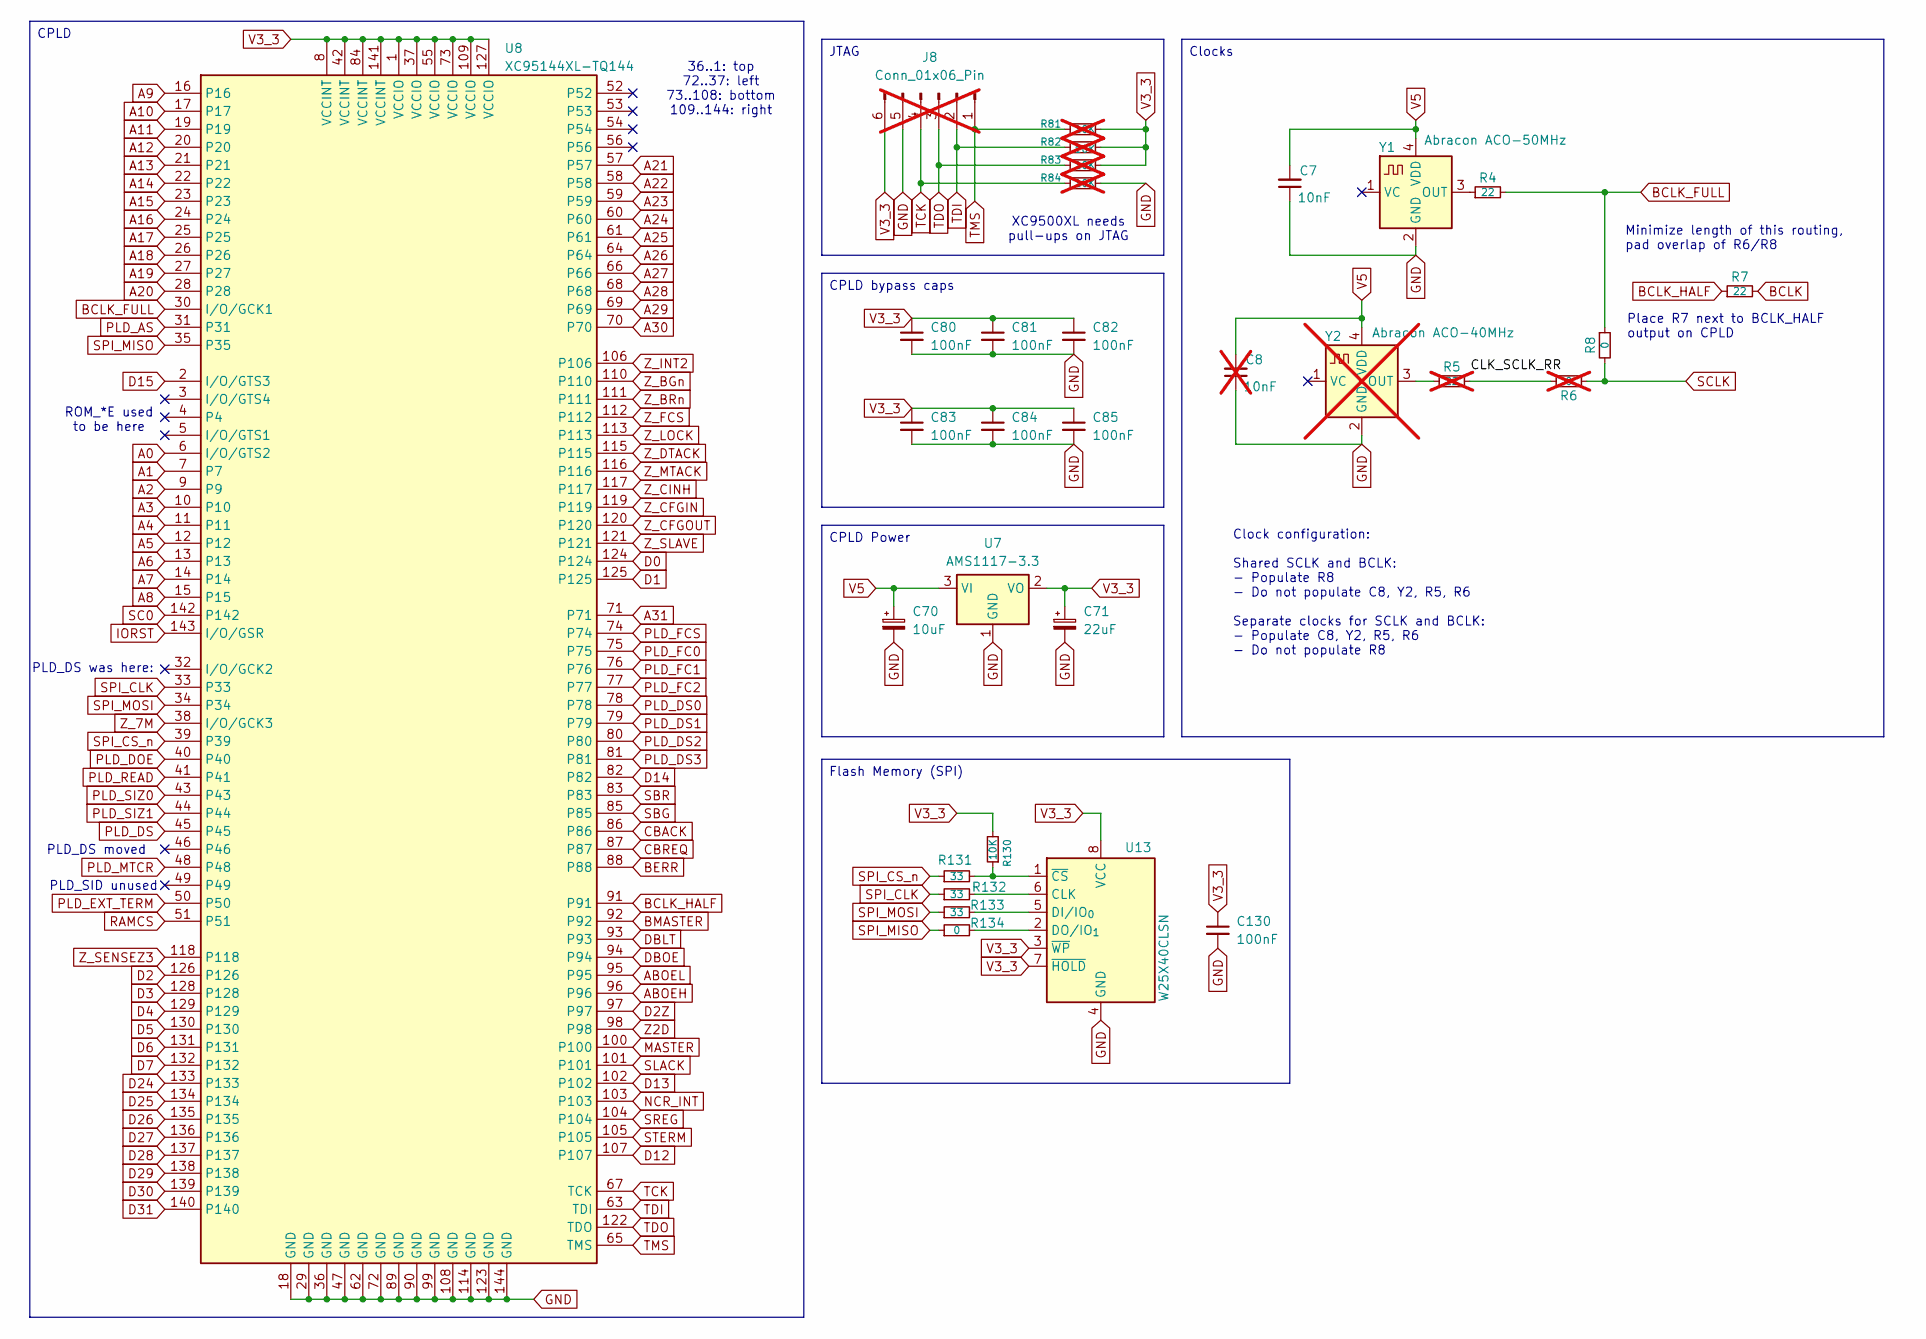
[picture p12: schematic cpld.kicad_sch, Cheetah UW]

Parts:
C7: 10nF; C_0603_1608Metric_Pad1.08x0.95mm_HandSolder; LCSC Part # C57112
C8: 10nF; C_0603_1608Metric_Pad1.08x0.95mm_HandSolder; LCSC Part # C57112; not fitted
C70: 10uF; CP_EIA-3528-15_AVX-H_HandSolder; LCSC Part # C7194
C71: 22uF; CP_EIA-3528-15_AVX-H_HandSolder; LCSC Part # C696813
C80, C81, C82, C83, C84, C85, C130: 100nF; C_0603_1608Metric_Pad1.08x0.95mm_HandSolder; LCSC Part # C14663
J8: Conn_01x06_Pin; PinHeader_1x06_P2.54mm_Vertical; LCSC Part # C6332199; not fitted
R4, R7: 22; R_0603_1608Metric; LCSC Part # C23345
R5: 22; R_0603_1608Metric; LCSC Part # C23345; not fitted
R6: 0; R_0603_1608Metric; LCSC Part # C21189; not fitted
R8, R134: 0; R_0603_1608Metric; LCSC Part # C21189
R81, R82, R83, R84: 10K; R_0603_1608Metric_Pad0.98x0.95mm_HandSolder; LCSC Part # C25804; not fitted
R130: 10K; R_0603_1608Metric_Pad0.98x0.95mm_HandSolder; LCSC Part # C25804
R131, R132, R133: 33; R_0603_1608Metric; LCSC Part # C23140
U7: AMS1117-3.3; SOT-223-3_TabPin2; LCSC Part # C6186
U8: XC95144XL-TQ144; TQFP-144_20x20mm_P0.5mm; LCSC Part # C1521137
U13: W25X40CLSN; SOIC-8_multi; LCSC Part # C19617
Y1: Abracon ACO-50MHz; Oscillator_SMD_Fox_FT5H_5.0x3.2mm; LCSC Part # C7431196
Y2: Abracon ACO-40MHz; Oscillator_SMD_Fox_FT5H_5.0x3.2mm; LCSC Part # C7431196; not fitted

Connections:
A0: U8.6 (I/O/GTS2); also elsewhere on the board
A1: U8.7; also elsewhere on the board
A2: U8.9; also elsewhere on the board
A3: U8.10; also elsewhere on the board
A4: U8.11; also elsewhere on the board
A5: U8.12; also elsewhere on the board
A6: U8.13; also elsewhere on the board
A7: U8.14; also elsewhere on the board
A8: U8.15; also elsewhere on the board
A9: U8.16; also elsewhere on the board
A10: U8.17; also elsewhere on the board
A11: U8.19; also elsewhere on the board
A12: U8.20; also elsewhere on the board
A13: U8.21; also elsewhere on the board
A14: U8.22; also elsewhere on the board
A15: U8.23; also elsewhere on the board
A16: U8.24; also elsewhere on the board
A17: U8.25; also elsewhere on the board
A18: U8.26; also elsewhere on the board
A19: U8.27; also elsewhere on the board
A20: U8.28; also elsewhere on the board
A21: U8.57; also elsewhere on the board
A22: U8.58; also elsewhere on the board
A23: U8.59; also elsewhere on the board
A24: U8.60; also elsewhere on the board
A25: U8.61; also elsewhere on the board
A26: U8.64; also elsewhere on the board
A27: U8.66; also elsewhere on the board
A28: U8.68; also elsewhere on the board
A29: U8.69; also elsewhere on the board
A30: U8.70; also elsewhere on the board
A31: U8.71; also elsewhere on the board
ABOEH: U8.96; also elsewhere on the board
ABOEL: U8.95; also elsewhere on the board
BCLK: R7.2; also elsewhere on the board
BCLK_FULL: R4.2, R8.1, U8.30 (I/O/GCK1)
BCLK_HALF: R7.1, U8.91
BERR: U8.88; also elsewhere on the board
BMASTER: U8.92; also elsewhere on the board
CBACK: U8.86; also elsewhere on the board
CBREQ: U8.87; also elsewhere on the board
D0: U8.124; also elsewhere on the board
D1: U8.125; also elsewhere on the board
D2: U8.126; also elsewhere on the board
D2Z: U8.97; also elsewhere on the board
D3: U8.128; also elsewhere on the board
D4: U8.129; also elsewhere on the board
D5: U8.130; also elsewhere on the board
D6: U8.131; also elsewhere on the board
D7: U8.132; also elsewhere on the board
D12: U8.107; also elsewhere on the board
D13: U8.102; also elsewhere on the board
D14: U8.82; also elsewhere on the board
D15: U8.2 (I/O/GTS3); also elsewhere on the board
D24: U8.133; also elsewhere on the board
D25: U8.134; also elsewhere on the board
D26: U8.135; also elsewhere on the board
D27: U8.136; also elsewhere on the board
D28: U8.137; also elsewhere on the board
D29: U8.138; also elsewhere on the board
D30: U8.139; also elsewhere on the board
D31: U8.140; also elsewhere on the board
DBLT: U8.93; also elsewhere on the board
DBOE: U8.94; also elsewhere on the board
GND: C7.1, C8.1, C70.2, C71.2, C80.2, C81.2, C82.2, C83.2, C84.2, C85.2, C130.2, J8.5, R84.1, U7.1 (GND), U8.18 (GND), U8.29 (GND), U8.36 (GND), U8.47 (GND), U8.62 (GND), U8.72 (GND), U8.89 (GND), U8.90 (GND), U8.99 (GND), U8.108 (GND), U8.114 (GND), U8.123 (GND), U8.144 (GND), U13.4 (GND), Y1.2 (GND), Y2.2 (GND); also elsewhere on the board
IORST: U8.143 (I/O/GSR); also elsewhere on the board
MASTER: U8.100; also elsewhere on the board
NCR_INT: U8.103; also elsewhere on the board
unnamed: R5.2, R6.2
unnamed: R132.2, U13.6 (CLK)
unnamed: R133.2, U13.5 (DI/IO_{0})
unnamed: R134.2, U13.2 (DO/IO_{1})
unnamed: R130.1, R131.2, U13.1 (~CS)
unnamed: R4.1, Y1.3 (OUT)
unnamed: R5.1, Y2.3 (OUT)
PLD_AS: U8.31; also elsewhere on the board
PLD_DOE: U8.40; also elsewhere on the board
PLD_DS: U8.45; also elsewhere on the board
PLD_DS0: U8.78; also elsewhere on the board
PLD_DS1: U8.79; also elsewhere on the board
PLD_DS2: U8.80; also elsewhere on the board
PLD_DS3: U8.81; also elsewhere on the board
PLD_EXT_TERM: U8.50; also elsewhere on the board
PLD_FC0: U8.75; also elsewhere on the board
PLD_FC1: U8.76; also elsewhere on the board
PLD_FC2: U8.77; also elsewhere on the board
PLD_FCS: U8.74; also elsewhere on the board
PLD_MTCR: U8.48; also elsewhere on the board
PLD_READ: U8.41; also elsewhere on the board
PLD_SIZ0: U8.43; also elsewhere on the board
PLD_SIZ1: U8.44; also elsewhere on the board
RAMCS: U8.51; also elsewhere on the board
SBG: U8.85; also elsewhere on the board
SBR: U8.83; also elsewhere on the board
SC0: U8.142; also elsewhere on the board
SCLK: R6.1, R8.2; also elsewhere on the board
SLACK: U8.101; also elsewhere on the board
SPI_CLK: R132.1, U8.33
SPI_CS_n: R131.1, U8.39
SPI_MISO: R134.1, U8.35
SPI_MOSI: R133.1, U8.34
SREG: U8.104; also elsewhere on the board
STERM: U8.105; also elsewhere on the board
TCK: J8.4, R84.2, U8.67 (TCK)
TDI: J8.2, R82.2, U8.63 (TDI)
TDO: J8.3, R83.2, U8.122 (TDO)
TMS: J8.1, R81.2, U8.65 (TMS)
V3_3: C71.1, C80.1, C81.1, C82.1, C83.1, C84.1, C85.1, C130.1, J8.6, R81.1, R82.1, R83.1, R130.2, U7.2 (VO), U8.1 (VCCIO), U8.8 (VCCINT), U8.37 (VCCIO), U8.42 (VCCINT), U8.55 (VCCIO), U8.73 (VCCIO), U8.84 (VCCINT), U8.109 (VCCIO), U8.127 (VCCIO), U8.141 (VCCINT), U13.3 (~WP), U13.7 (~HOLD), U13.8 (VCC); also elsewhere on the board
V5: C7.2, C8.2, C70.1, U7.3 (VI), Y1.4 (VDD), Y2.4 (VDD); also elsewhere on the board
Z2D: U8.98; also elsewhere on the board
Z_7M: U8.38 (I/O/GCK3); also elsewhere on the board
Z_BGn: U8.110; also elsewhere on the board
Z_BRn: U8.111; also elsewhere on the board
Z_CFGIN: U8.119; also elsewhere on the board
Z_CFGOUT: U8.120; also elsewhere on the board
Z_CINH: U8.117; also elsewhere on the board
Z_DTACK: U8.115; also elsewhere on the board
Z_FCS: U8.112; also elsewhere on the board
Z_INT2: U8.106; also elsewhere on the board
Z_LOCK: U8.113; also elsewhere on the board
Z_MTACK: U8.116; also elsewhere on the board
Z_SENSEZ3: U8.118; also elsewhere on the board
Z_SLAVE: U8.121; also elsewhere on the board

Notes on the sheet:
Clock configuration: Shared SCLK and BCLK: - Populate R8 - Do not populate C8, Y2, R5, R6 Separate clocks for SCLK and BCLK: - Populate C8, Y2, R5, R6 - Do not populate R8
PLD_SID unused
PLD_DS moved
ROM_*E used to be here
Minimize length of this routing, pad overlap of R6/R8
36..1: top 72..37: left 73..108: bottom 109..144: right
Place R7 next to BCLK_HALF output on CPLD
XC9500XL needs pull-ups on JTAG
PLD_DS was here:
CPLD
Clocks
JTAG
CPLD Power
CPLD bypass caps
Flash Memory (SPI)

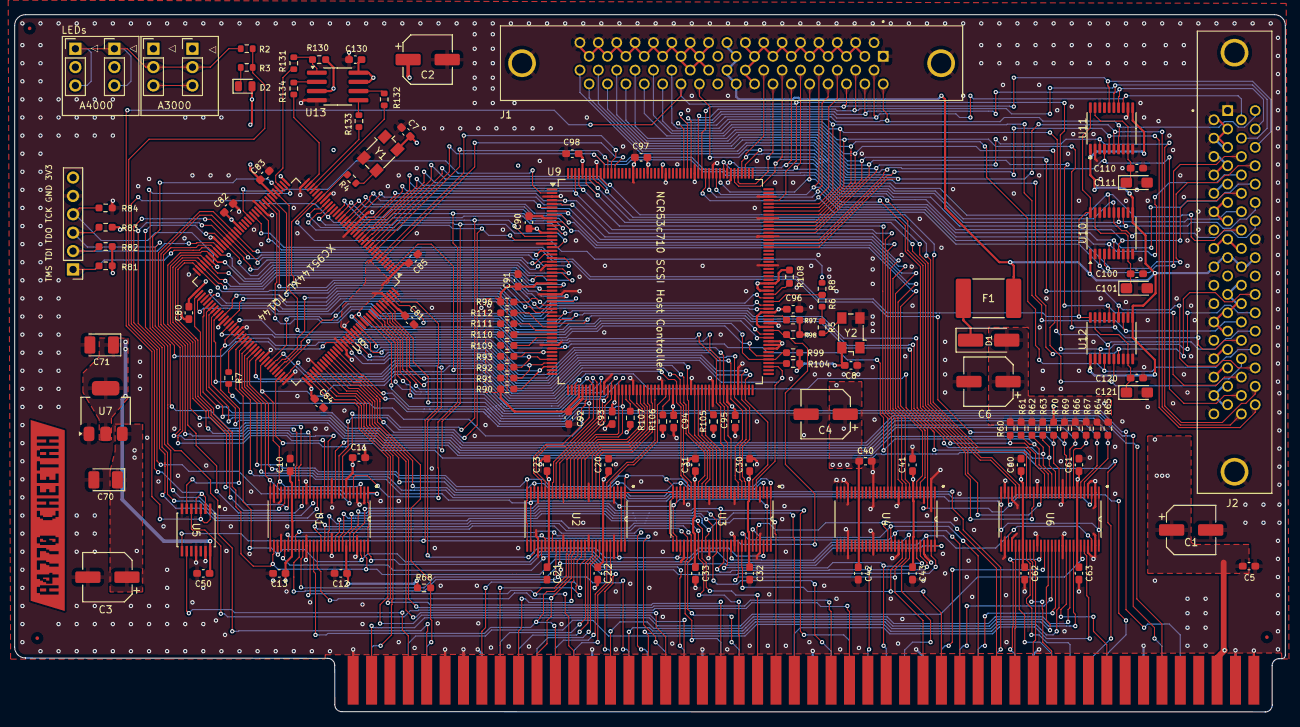
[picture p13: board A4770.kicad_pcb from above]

Board: 4 copper layers, 175.6 x 96.4 mm, 127 parts (0 on the bottom side), 231 nets.

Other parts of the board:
kibuzzard-696E6D75: G***; kibuzzard-696E6D75

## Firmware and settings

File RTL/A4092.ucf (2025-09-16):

# P1 - VCCIO
NET "D<15>"       LOC = "P2";
NET "ROM_CE_n"    LOC = "P3";
NET "ROM_WE_n"    LOC = "P4";
NET "ROM_OE_n"    LOC = "P5";
NET "AL<0>"        LOC = "P6";
NET "AL<1>"        LOC = "P7";
# P8 - VCCINT
NET "A<2>"        LOC = "P9";
NET "A<3>"        LOC = "P10";
NET "A<4>"        LOC = "P11";
NET "A<5>"        LOC = "P12";
NET "A<6>"        LOC = "P13";
NET "A<7>"        LOC = "P14";
NET "A<8>"        LOC = "P15";
NET "A<9>"        LOC = "P16";
NET "A<10>"       LOC = "P17";
# P18 - GND
NET "A<11>"       LOC = "P19";
NET "A<12>"       LOC = "P20";
NET "A<13>"       LOC = "P21";
NET "A<14>"       LOC = "P22";
NET "A<15>"       LOC = "P23";
NET "A<16>"       LOC = "P24";
NET "A<17>"       LOC = "P25";
NET "A<18>"       LOC = "P26";
NET "A<19>"       LOC = "P27";
NET "A<20>"       LOC = "P28";
# P29 - GND
NET "CLK_50M"     LOC = "P30";
NET "CLK_50M" TNM_NET = "clk";
TIMESPEC "TS_clk" = PERIOD "clk" 20 ns HIGH 50%;
NET "SCSI_AS_n"   LOC = "P31";
NET "SCSI_DS_n"   LOC = "P32";
NET "SPI_CLK"     LOC = "P33";
NET "SPI_MOSI"    LOC = "P34";
NET "SPI_MISO"    LOC = "P35";
# P36 - GND
# P37 - VCCIO
NET "C7M"         LOC = "P38";
NET "C7M"         TNM_NET = "C7M";
TIMESPEC "TS_C7M" = PERIOD "C7M" 139.68 ns HIGH 50%;
NET "SPI_CS_n"    LOC = "P39";
NET "DOE"         LOC = "P40";
NET "READ"        LOC = "P41";
# P42 - VCCINT
NET "SIZ<0>"      LOC = "P43";
NET "SIZ<1>"      LOC = "P44";
# P45 - NC
# P46 - NC
# P47 - GND
NET "MTCR_n"      LOC = "P48";
NET "SID_n"       LOC = "P49";
NET "DIP_EXT_TERM" LOC = "P50";
# P51 - NC
NET "test"        LOC = "P52";
# P52 - NC
# P53 - NC
# P54 - NC
# P55 - VCCIO
# P56 - NC
# P57 - NC
# P58 - NC
NET "A<23>"       LOC = "P59";
NET "A<24>"       LOC = "P60";
NET "A<25>"       LOC = "P61";
# P62 - GND
# P63 - TDI
NET "A<26>"       LOC = "P64";
# P65 - TMS
NET "A<27>"       LOC = "P66";
# P67 - TCK
NET "A<28>"       LOC = "P68";
NET "A<29>"       LOC = "P69";
NET "A<30>"       LOC = "P70";
NET "A<31>"       LOC = "P71";
# P72 - GND
# P73 - VCCIO
NET "FCS" 	      LOC = "P74";
NET "FC<0>"       LOC = "P75";
NET "FC<1>"       LOC = "P76";
NET "FC<2>"       LOC = "P77";
NET "DS_n<0>"     LOC = "P78";
NET "DS_n<1>"     LOC = "P79";
NET "DS_n<2>"     LOC = "P80";
NET "DS_n<3>"     LOC = "P81";
NET "D<14>"       LOC = "P82";
NET "SBR_n"       LOC = "P83";
# P84 - VCCINT
NET "SBG_n"       LOC = "P85";
NET "CBACK_n"     LOC = "P86";
NET "CBREQ_n"     LOC = "P87";
NET "BERR_n"      LOC = "P88";
# P89 - GND
# P90 - GND
NET "CLK"         LOC = "P91";
NET "BMASTER"     LOC = "P92";
NET "DBLT"        LOC = "P93";
NET "DBOE_n"      LOC = "P94";
NET "ABOEL_n"     LOC = "P95";
NET "ABOEH_n"     LOC = "P96";
NET "D2Z_n"       LOC = "P97";
NET "Z2D_n"       LOC = "P98";
# P99 - GND
NET "MASTER_n"    LOC = "P100";
NET "SLACK_n"     LOC = "P101";
NET "D<13>"       LOC = "P102";
NET "SINT_n"      LOC = "P103";
NET "SCSI_SREG_n" LOC = "P104";
NET "SCSI_STERM_n" LOC = "P105";
NET "INT2_n"      LOC = "P106";
NET "INT2_n"      SLEW = "SLOW";
NET "D<12>"       LOC = "P107";
# P108 - GND
# P109 - VCCIO
NET "BGn"         LOC = "P110";
NET "BRn"         LOC = "P111";
NET "BRn"      	SLEW = "SLOW";
NET "Z_FCS_n"     LOC = "P112";
NET "Z_FCS_n"     SLEW = "SLOW";
NET "Z_LOCK"      LOC = "P113";
# P114 - GND
NET "DTACK_n"     LOC = "P115";
NET "DTACK_n"     SLEW = "SLOW";
NET "MTACK_n"     LOC = "P116";
NET "CINH_n"      LOC = "P117";
NET "CINH_n"      SLEW = "SLOW";
NET "SENSEZ3"     LOC = "P118";
NET "CFGIN_n"     LOC = "P119";
NET "CFGOUT_n"    LOC = "P120";
NET "CFGOUT_n"    SLEW = "SLOW";
NET "SLAVE_n"     LOC = "P121";
NET "SLAVE_n"     SLEW = "SLOW";
# P122 - TDO
# P123 - GND
NET "D<0>"        LOC = "P124";
NET "D<1>"        LOC = "P125";
NET "D<2>"        LOC = "P126";
# P127 - VCCIO
NET "D<3>"        LOC = "P128";
NET "D<4>"        LOC = "P129";
NET "D<5>"        LOC = "P130";
NET "D<6>"        LOC = "P131";
NET "D<7>"        LOC = "P132";
NET "D<24>"       LOC = "P133";
NET "D<25>"       LOC = "P134";
NET "D<26>"       LOC = "P135";
NET "D<27>"       LOC = "P136";
NET "D<28>"       LOC = "P137";
NET "D<29>"       LOC = "P138";
NET "D<30>"       LOC = "P139";
NET "D<31>"       LOC = "P140";
# P141 - VCCINT
NET "SC0"			LOC = "P142";
NET "IORST_n"     LOC = "P143";
NET "IORST_n" TIG;  # Ignore timing on async reset
# P144 - GND

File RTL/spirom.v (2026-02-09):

`timescale 1ns / 1ps
//////////////////////////////////////////////////////////////////////////////////
// Company:
// Engineer:
//
// Create Date:    20:21:44 08/03/2025
// Design Name:
// Module Name:    spirom
// Project Name:
// Target Devices:
// Tool versions:
// Description:
//
// Dependencies:
//
// Revision:
// Revision 0.01 - File Created
// Additional Comments:
//
//////////////////////////////////////////////////////////////////////////////////
module spirom(
    input clk,
    input IORST_n,
    input romcycle,
    input [22:2] addr,
    input DOE,
    input [3:0] DS_n,
    input READ,
    input FC2,
    output reg dtack = 0,
    output reg spi_read = 0,
    output reg [7:0] spi_dataout = 0,
    input [7:0] spi_datain,
    output reg SPI_CLK = 0,
    output reg SPI_CS_n = 1,
    output reg SPI_MOSI = 0,
    input SPI_MISO
    );

    localparam  SPI_IDLE    =  0,
                SPI_N       =  1,
                SPI_P       =  2,
                SPI_DTACK   =  3;

    (* fsm_encoding = "gray" *)reg [2:0] spi_state = SPI_IDLE;
    reg [5:0] cnt = 40;
    wire [39:0] readcmd;
    reg close = 1;

    reg romcycle_sync = 0;
    reg doe_sync = 0;
    reg DS_sync = 0;

    assign readcmd = {8'h03, 3'b000, addr[22:2], spi_datain};

    always @ (negedge IORST_n, posedge clk) begin
        if (!IORST_n) begin
            romcycle_sync <= 0;
            doe_sync <= 0;
            DS_sync <= 0;
        end else begin
            romcycle_sync <= romcycle;
            doe_sync <= DOE;
            DS_sync <= ~&DS_n;
        end
    end

    always @ (negedge IORST_n, posedge clk) begin
        if (!IORST_n) begin
            cnt <= 40;
            spi_read <= 0;
            dtack <= 0;
            SPI_CLK <= 0;
            SPI_CS_n <= 1;
            SPI_MOSI <= 0;
            close <= 1;
            spi_state <= SPI_IDLE;
        end else begin
            spi_read <= 0;
            dtack <= 0;
            SPI_CLK <= 0;
            SPI_MOSI <= 0;
            case (spi_state)
            SPI_IDLE : begin
                spi_state <= SPI_IDLE;
                if (romcycle_sync && ~&addr[22:4]) begin            // access to ROM area
                    SPI_CS_n <= 1;
                    close <= 1;
                    cnt <= 40;
                    if (READ) begin
                        spi_state <= SPI_N;                         // READ -> Start SPI read command
                    end else begin
                        spi_state <= SPI_DTACK;                     // WRITE -> immediately end ZIII Cycle
                    end
                end else if (romcycle_sync && &addr[22:4]) begin    // access to control Register
                    close <= addr[2];
                    cnt <= 8;
                    if (READ) begin
                        spi_state <= SPI_N;                         // READ -> immediately start SPI cycle
                    end else if (doe_sync && DS_sync) begin
                        spi_state <= SPI_N;                         // WRITE -> wait for DOE and DS before start SPI cycle
                    end
                end
            end
            SPI_N : begin
                SPI_CS_n <= 0;
                if (cnt == 0) begin
                    spi_read <= READ;
                    spi_state <= SPI_DTACK;
                end else begin
                    if (cnt > 8 || !READ) begin
                        SPI_MOSI <= readcmd[cnt-1];
                    end
                    spi_state <= SPI_P;
                end
            end
            SPI_P : begin
                SPI_CLK <= 1;
                if (cnt <= 8 && READ) begin
                    spi_dataout <= {spi_dataout[6:0], SPI_MISO};
                end else begin
                    spi_dataout <= 0;
                end
                cnt <= cnt -1;
                spi_state <= SPI_N;
            end
            SPI_DTACK : begin
                SPI_CS_n <= close;
                if (!romcycle_sync) begin
                    spi_read <= 0;
                    dtack <= 0;
                    spi_state <= SPI_IDLE;
                end else begin
                    spi_read <= READ;
                    dtack <= 1;
                    spi_state <= SPI_DTACK;
                end
            end
            endcase
        end
     end

endmodule

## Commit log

2025-07-14 Fixup address decodes
    *_region was matching when slave_cycle was true but without checking that the base address matched - this would cause these regions to match when other Z3 boards are being accessed
2025-07-14 Add Schematics for Rev-A and move Production files to REV-A directory
    [bom.csv, designators.csv, positions.csv]
2025-07-14 Update pin setup
    - SENSEZ3_n -> SENSEZ3
    - Adjust SLEW rates (although SLOW is default in Makefile
    - Set unused pins to float for now.
    - Add SC0
2025-07-14 Clean up address handling
    - only the memory map needs all address pins, intreg already uses
    interrupt_region
    - Keep disconnected pins A21/A22 0 for address comparisons or we can't
    match any regions.
2025-07-27 Enhanced NVRAM Commands
    The -F option now supports flexible comma-separated combinations:
    Single Operations:
    * a4092flash -F init - Initialize NVRAM partition
    * a4092flash -F osflags - Read os_flags,
    * a4092flash -F switchflags - Read switch_flags,
    * a4092flash -F osflags=ff - Write os_flags,
    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
2025-07-31 KiCAD: Add SCSI Flipper
    [Flipper.kicad_pcb, Flipper.kicad_sch]
2025-08-03 a4092flash: Drop 3.3V only parts
2025-08-03 a4092flash: Don't inhibit devices during flashing
    On some lideflash supported devices flash memory and register space
    is shared. Because of that it has to make sure no reads/writes are
    going on while the flashing is in progress.
    On the A4092 however, the host controller registers live separately from
    flash memory.
2025-08-04 a4092flash: Refactor NVRAM operations
    - Fix printf format specifiers for ULONG addresses using explicit casts
    - Split NVRAM command handling into separate parse and execute phases
    - Add nvramParams structure to store parsed NVRAM operation parameters
    - Move NVRAM execution to after board initialization for proper flash access
    - Replace direct NVRAM_OFFSET usage with board->flashbase + NVRAM_OFFSET
    This improves code organization and ensures NVRAM operations have proper
    access to the flash memory through the initialized board structure.
2025-09-19 RTL: SPI fixes
2025-09-28 Update Schematics and PCB with fixes for known issues
    This commit fixes:
    * U4 enable IORST -> ABOEH
    * U5 VCC 5V -> 3.3V
    [zorro3.kicad_sch]
2025-10-05 Kicad: Add dual footprint for 150mil and 208mil SPI parts
2025-10-05 Add 68pin SCSI connectors
2025-10-29 First version of A4770 cheetah
    [A4092.kicad_sch, Termination.kicad_sch, flash.kicad_sch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]
2025-10-29 Drop obsolete files
    [flash.kicad_sch, power.kicad_sch]
2025-10-29 Drop old files
    [A4092_0418.kicad_pcb, A4092_0419.kicad_pcb]
2025-11-13 Add series resistors for SPI
    [cpld.kicad_sch]
2025-12-09 Placement updated with latest netlist
    [A4092.kicad_pcb]
2025-12-17 Placement updates -SCSI moved south
    [A4092.kicad_pcb]
2025-12-17 CPLD Placement changes
    [A4092.kicad_pcb]
2025-12-17 Initial routing and signal clean up
    [A4092.kicad_pcb]
2026-01-06 J2 rotated by 180, imported netlist, routing
    [A4092.kicad_pcb]
2026-01-09 CPLD Routing
    [A4092.kicad_pcb]
2026-01-09 Fix NCR53C770 footprint
    P119 (Vss) was not in correctly assigned in the footprint.
    Added it, and connected to Vss.
    [scsi2.kicad_sch]
2026-01-09 Mark PLD_SID as NC on U8
    Pin 91 on U8 (PLD_SID) is now unused because there is no
    more DIP switch logic on the board.
    [cpld.kicad_sch]
2026-01-09 Update PCB from Schematic
    [A4092.kicad_pcb]
2026-01-09 Adjust back side silkscreen on PCB
    [A4092.kicad_pcb]
2026-01-10 Undo last two PCB changes
    [A4092.kicad_pcb]
2026-01-10 Update PCB from Schematic
    (adds series resistors for SPI)
    [A4092.kicad_pcb]
2026-01-10 CPLD Routing WIP
    [A4092.kicad_pcb]
2026-01-10 Undo Update PCB from Schematics
    [A4092.kicad_pcb]
2026-01-10 Series resistor for MISO 33O -> 0O
    [cpld.kicad_sch]
2026-01-10 U6: Switch from 74ABT16245 to 74ABT16543
    This increases the number of 74ABT16543 parts used and gets rid of the
    74ABT16245 all together, which overall lowers BOM cost despite the 74ABT16245
    being a bit cheaper in single quantities. Given that U6 is also the only part
    we know of that got killed in a Zorro accident pulling the board out of a
    running machine, using a part we are more likely to have spares makes sense.
    [zorro3.kicad_sch]
2026-01-11 Reverse pin order on U6
    the pin lineup changed between 16245 and 16543. Switching the pins around
    will make it easier to reroute to the new chip.
    [zorro3.kicad_sch]
2026-01-11 Fix footprint table to not have hardcoded paths
2026-01-12 Imported netlist and general routing
    [A4092.kicad_pcb]
2026-01-12 U9 data routing
    [A4092.kicad_pcb]
2026-01-14 Clean up pull-up resistors
    [Termination.kicad_sch, scsi2.kicad_sch, zorro3.kicad_sch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]
2026-01-14 General routing
    [A4092.kicad_pcb]
2026-01-18 Fix description and part numbers for SCSI connectors
    Was still using the description for SCSI-2
    [Termination.kicad_sch]
2026-01-18 Add more clarity around clock circuit
    [cpld.kicad_sch]
2026-01-18 Tie DIFFSENS to GND not V5
    [scsi2.kicad_sch]
2026-01-18 Revert false change, DIFFSENS -> V5
    [scsi2.kicad_sch]
2026-01-19 Fix up graphics in PCB
    [A4092.kicad_pcb]
2026-01-23 PWR and GND routing
    [A4092.kicad_pcb]
2026-01-24 Rehaul clock circuit in schematics
    and try to add most of the LCSC part numbers
    [Termination.kicad_sch, scsi2.kicad_sch, zorro3.kicad_sch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]
2026-01-24 Rename board from A4092 to A4770
    [A4770.kicad_pcb, A4770.kicad_sch, Termination.kicad_sch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]
2026-01-25 CLK placement and routing
    [A4770.kicad_pcb]
2026-01-26 U2 placement and routing improvements
    [A4770.kicad_pcb]
2026-01-29 Ruouting completed
    [A4770.kicad_pcb]
2026-01-30 Board cleanup
    [A4770.kicad_pcb]
2026-01-31 Silkscreen fixes
    [A4770.kicad_pcb]
2026-02-03 J2 rotated by 180 degree, placement and routing updates
    [A4770.kicad_pcb]
2026-02-03 DRCs checks
    [A4770.kicad_pcb]
2026-02-03 Remove SCLK from CPLD
    [cpld.kicad_sch]
2026-02-05 Imported latest netlist, teardrops, stitching vias, DRCs checks
    [A4770.kicad_pcb]
2026-02-05 Update Gerbers, Schematics and README.md
    [bom.csv, designators.csv, positions.csv]
2026-02-06 Fix issues detected by JLCPCB's uploader
    - Use alternating decoupling caps of 0.01uF and 0.1uF on the
    NCR53c770 as was done on the A4091 design.
    - Remove DNP parts from BOM
    - Remove fiducials from position files.
    [A4770.kicad_pcb, scsi2.kicad_sch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]
2026-02-06 Fix footprints
    [A4770.kicad_pcb, zorro3.kicad_sch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]
2026-02-07 Remove Flipper
    It does not make sense for this design
    [Flipper.kicad_pcb, Flipper.kicad_sch]
2026-02-09 Changes from schematics review 26-02-08
    [Termination.kicad_sch, scsi2.kicad_sch]
2026-02-11 Update TERMPWR diode to DSS34
    [Termination.kicad_sch]
2026-02-12 Implemented design feedback from final checks
    [A4770.kicad_pcb]
2026-02-15 Fix up part numbers
    [A4770.kicad_pcb, Termination.kicad_sch]
